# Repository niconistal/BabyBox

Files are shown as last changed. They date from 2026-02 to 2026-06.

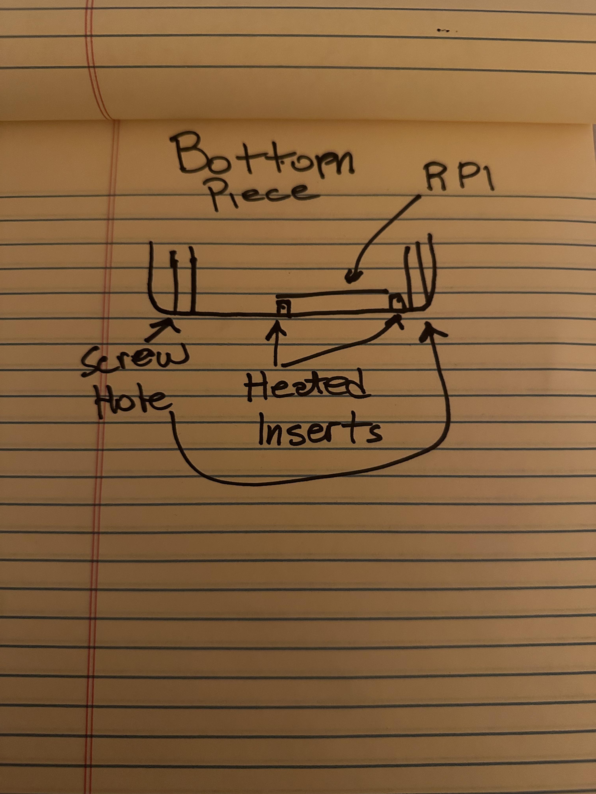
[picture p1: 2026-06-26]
hardware/sketches/sketch-bottom-piece.jpeg

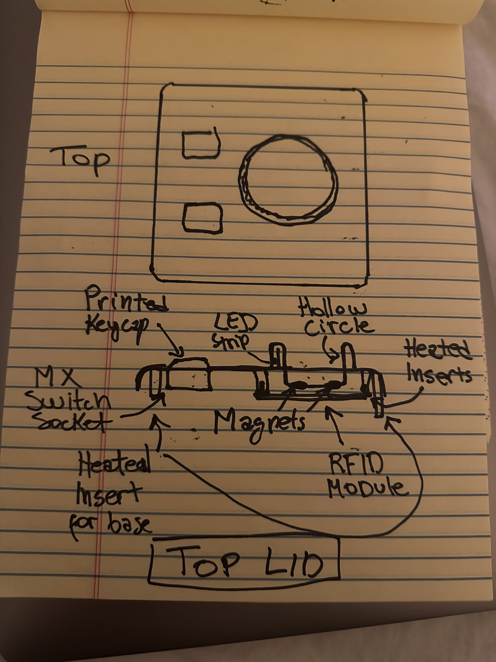
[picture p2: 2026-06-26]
hardware/sketches/sketch-top-and-lid.jpeg

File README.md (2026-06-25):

<div align="center">

# 🧸 BabyBox

### A screen-free, figurine-driven media player for toddlers

*Place a 3D-printed character on the box — its song or video plays. No menus, no screens, no swiping.*

BabyBox render — a soft white box with a glowing rainbow LED strip and a pink figurine on top








</div>

---

## What it is

BabyBox is a tangible, Montessori-friendly media player built around a Raspberry Pi. A child plays content by **physically placing a figurine** on top of the box — each figurine hides an RFID tag and magnets, so it snaps into place and is detected instantly. Parents curate content from a phone or laptop via a web UI; kids interact with nothing but the toys.

It's a full-stack hardware project: **embedded software, a parent web app, parametric 3D-printed hardware, and the audio/Bluetooth plumbing** to tie it together.

> [!NOTE]
> This is a personal/portfolio build. It demonstrates end-to-end ownership of a physical product — from OpenSCAD CAD and GPIO wiring up through a tested Python service and a Flask UI — including a hardware-abstraction layer that lets the entire system run and be tested **on a laptop with no Raspberry Pi attached**.

---

## How it works

```
   Figurine                Raspberry Pi Zero 2 W
 (RFID + magnets)     ┌───────────────────────────┐
        │             │                           │
        ▼   SPI       │   ┌─────────┐             │──── HDMI ───► TV   (video only)
   ┌─────────┐  ┌────►│   │   mpv   │  playback   │
   │ box top │──┘     │   └─────────┘             │──── BT A2DP ► Speaker (all audio)
   │ RFID +  │        │                           │
   │ magnets │        │   Flask web UI  ◄── WiFi ─┼──── 📱 Parent's phone / laptop
   └─────────┘        └───────────────────────────┘
```

1. **Tap to play** — a figurine is placed; the MFRC522 reader picks up its RFID UID.
2. **Map & play** — the controller looks up the tag → media mapping (SQLite) and plays it with `mpv`.
3. **Split A/V** — video goes to the TV over HDMI; *all* audio is routed to a Bluetooth speaker (placed near the child at a safe volume).
4. **Playback lock** — once content starts, new figurines are ignored until it finishes. No toddler content-hopping.
5. **Parents stay in control** — a web UI handles YouTube downloads (`yt-dlp`), figurine assignment, daily video limits, and history.

---

## Highlights

| | |
|---|---|
| 🎯 **Zero-screen interface for kids** | The only "UI" a toddler touches is a physical toy. RFID + magnets give a satisfying snap and reliable reads. |
| 🔌 **Mock/real hardware abstraction** | A factory + `base` interfaces swap real GPIO drivers for mocks via `BABYBOX_ENV=dev`. The whole stack runs and is unit-tested off-Pi. |
| 📺 **Split audio/video routing** | Picture on the TV (HDMI), sound on a portable Bluetooth speaker — solved with a non-trivial PipeWire/WirePlumber config. |
| ⏳ **Real parental controls** | Per-day video limits (count *and* minutes), 6 AM reset, audio always unlimited, with gentle LED + buzzer "last video / all done" feedback. |
| 🧩 **Parametric 3D-printed hardware** | OpenSCAD enclosure + figurine bases with pause-and-insert magnet pockets (fully sealed = toddler-safe). Includes a custom "burgerdog" multi-color mascot. |
| 🧠 **Robust by design** | Falls back to HDMI audio if the speaker is off; de-dupes rapid RFID reads; a finite-state playback machine keeps behavior predictable. |

---

## Tech stack

| Layer | Tech |
|---|---|
| **Core service** | Python 3, threaded RFID/button loops, FSM controller |
| **Media** | `yt-dlp` (download) · `mpv` via `python-mpv` (playback) |
| **Audio** | PipeWire + WirePlumber (Bluetooth A2DP, no-suspend config) |
| **Hardware** | MFRC522 RFID (SPI) · WS2812 LEDs · passive buzzer · 2 buttons |
| **Web UI** | Flask + vanilla HTML/JS (no build step) |
| **Storage** | SQLite (single file, zero-config) |
| **CAD** | OpenSCAD (parametric, code-defined) → STL → Bambu Studio |
| **Ops** | systemd services · `setup.sh` provisioning |
| **Tests** | pytest (controller, limits, db) |

---

## Getting started (dev mode — no Pi required)

The hardware layer mocks itself, so you can run the full service on macOS/Linux:

```bash
cd software
python -m venv .venv && source .venv/bin/activate
pip install -r requirements.txt

# Run with mock hardware + web UI
BABYBOX_ENV=dev BABYBOX_DATA_DIR=./_data python -m software.main
# → web UI at http://localhost:8080

# Run the test suite
pytest
```

In dev mode, "scanning a figurine" and button presses are simulated through the mock drivers, and media playback is stubbed — so you can exercise the controller, limits, and web UI end-to-end without any electronics.

### On the Raspberry Pi

```bash
# Raspberry Pi OS Lite — enable SPI, install system deps, BT config, systemd units
sudo ./scripts/setup.sh
```

This installs the Pi-only drivers (`mfrc522`, `rpi_ws281x`, `RPi.GPIO`), the WirePlumber Bluetooth fixes (`scripts/wireplumber/`), and registers the `babybox` + Bluetooth auto-connect services. The parent UI is then reachable at **`http://babybox.local`**.

---

## Repository layout

```
BabyBox/
├── software/            # Python service
│   ├── main.py          #   entry point — wires hardware, controller, web together
│   ├── controller.py    #   playback state machine + video-limit logic
│   ├── player.py        #   mpv wrapper (split A/V output)
│   ├── downloader.py    #   yt-dlp wrapper (MP4 video / MP3 audio)
│   ├── bluetooth.py     #   speaker pairing + auto-connect
│   ├── limits.py        #   daily video-limit enforcement
│   ├── db.py / models.py#   SQLite layer + data classes
│   ├── hardware/        #   ⭐ base interfaces + mock/ and real/ drivers (factory)
│   ├── web/             #   Flask app (dashboard, library, figurines, settings, history)
│   └── tests/           #   pytest suite
├── hardware/
│   ├── enclosure/       #   babybox-case.scad — parametric box
│   └── figurines/       #   base template + "burgerdog" multi-layer mascot
├── scripts/             #   setup.sh, systemd units, WirePlumber configs, STL gen
├── renders/             #   Blender renders + exported STLs
├── docs/                #   printable assembly guide (PDF + generator)
├── website/             #   marketing site (deployed via GitHub Pages)
└── SPEC.md              #   full design spec (hardware, software, BoM, decisions)
```

---

## Hardware (bill of materials)

Roughly **~$51** total if you already own a Bluetooth speaker:

Raspberry Pi Zero 2 W · MicroSD · MFRC522 RFID module + MIFARE coin stickers · WS2812 LED strip · passive buzzer · 2 buttons · neodymium magnets (6×3 mm) · 5V/3A supply · mini-HDMI cable · 3D-printed enclosure & figurines (Bambu Lab P2S).

Full BoM, GPIO pinout, wiring, and design rationale live in **[`SPEC.md`](SPEC.md)**.

---

## Design decisions worth calling out

- **Figurine = the interface.** RFID coin stickers are invisible to the child and embedded in the toy; magnets guarantee the tag lands over the antenna every time.
- **Magnets are sealed inside the print** using a pause-and-insert technique (solid layers above and below) — they cannot be removed or swallowed.
- **Audio over Bluetooth, not the Pi jack** — portable, volume-safe near the child, and frees GPIO 18 for the LED strip. The tradeoff was a finicky shared-radio Bluetooth stack, fixed with two WirePlumber configs.
- **Playback lock over a "stop and switch" model** — toddlers will otherwise swap figurines endlessly. Content must finish; the stop button is a parent escape hatch.
- **Code-defined CAD (OpenSCAD)** — the enclosure is parametric and diff-able, not a binary blob.

---

<div align="center">

*Built as a portfolio project — a small physical product taken from spec to (almost) toddler-tested.*

See **[`SPEC.md`](SPEC.md)** for the complete design document.

</div>

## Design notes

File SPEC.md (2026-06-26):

# BabyBox — Toddler Media Player

## Overview

BabyBox is a toddler-friendly media player powered by a Raspberry Pi. The child places
a 3D-printed figurine on top of the box to play a song or video. Each figurine has an
RFID tag and magnets embedded inside. The box has matching magnets and an RFID reader
under the top surface, so the figurine snaps into place and is detected instantly.

Parents add content by pasting YouTube URLs into a web UI. The system downloads
the video and saves it locally — either as video (MP4) or audio-only (MP3),
depending on what the parent chooses. A daily video limit prevents excessive screen
time while audio remains unrestricted.

**Output routing:** Video goes to the TV via HDMI. All audio goes to a Bluetooth
speaker. For video content, the picture is on the TV and the sound comes from the
Bluetooth speaker.

**Playback lock:** Once content starts playing, it must finish before a new figurine is
accepted. Figurines placed during playback are ignored. This prevents a toddler from
endlessly swapping between content.

---

## 1. User Stories

| Who | What |
|---|---|
| Child  | Places a figurine on the box and the associated song/video starts |
| Child  | Sees a fun LED animation when a figurine is placed |
| Child  | Places figurines during playback — nothing happens (content must finish)|
| Child  | Gets a "last video" warning (LED + buzzer) when 1 video remains |
| Child  | Gets a "all done" feedback (LED + buzzer) when video limit is reached |
| Parent | Pastes a YouTube URL, picks audio or video, system downloads it |
| Parent | 3D-prints figurines and embeds RFID tags + magnets |
| Parent | Assigns a figurine to a downloaded media file via the web UI |
| Parent | Sets a daily video limit (e.g., 3 videos or 45 min/day) |
| Parent | Sees playback history / daily stats on the web UI |

---

## 2. Hardware

### 2.1 Bill of Materials

| Component | Source | Est. Cost |
|---|---|---|
| Raspberry Pi Zero 2 W | Purchase | ~$15 |
| MicroSD card (32 GB+) | Purchase | ~$8 |
| MFRC522 RFID Module | Kit | -- |
| RFID sticker tags (MIFARE 13.56 MHz, 25mm coin type) | Purchase (10x) | ~$5 |
| Neodymium magnets (6x3mm disc, 20x) | Purchase  | ~$5 |
| Bluetooth speaker | Already owned / Purchase | ~$0-20 |
| WS2812B RGB 8-LED flexible strip (60/m, SunFounder kit) | Kit | -- |
| MX (Cherry-compatible) keyswitches (x2: play/pause, stop) | Purchase | ~$2 |
| Brass heat-set inserts (M3 x8, M2.5 x4, M2 x4)  | Purchase | ~$3 |
| M3 / M2.5 / M2 machine screws (assorted) | Purchase | ~$2 |
| Passive Buzzer | Kit | -- |
| Resistors / wires (soldered — no breadboard) | Kit | -- |
| 5V 3A micro USB power supply | Purchase | ~$8 |
| Mini HDMI to HDMI cable | Purchase | ~$5 |
| 3D-printed enclosure + figurines| Bambu Lab P2S | ~$5 |
| **Total (if speaker owned)** | | **~$56**  |

### 2.2 Why Pi Zero 2 W?

- Cheapest Pi with quad-core ARM (1 GHz) and hardware H.264 decode
- Built-in WiFi for the parent web UI (no extra dongles)
- Built-in Bluetooth for connecting to the speaker
- Enough GPIO for RFID, LEDs, buttons, and buzzer
- HDMI output for video to TV
- Runs headless Raspberry Pi OS Lite with minimal overhead

### 2.3 Output Routing

```
                    ┌──────────────┐
                    │  Raspberry   │
   Figurine         │  Pi Zero 2 W │
   (RFID + magnet)  │              │
     ▼         SPI  │  ┌────────┐  │──── HDMI ────► TV (video only)
   [Box top] ──────►│  │  mpv   │  │
                    │  └────────┘  │──── Bluetooth ► Speaker (all audio)
                    │              │
                    └──────────────┘
```

**Video content:** Picture on TV via HDMI, audio routed to Bluetooth speaker via
PulseAudio/PipeWire.

**Audio content:** Sound plays on Bluetooth speaker only. TV can be off or show an
idle screen.

**Why split?** The Bluetooth speaker can be placed near the child at a safe volume,
while the TV can be further away. Volume is controlled on the speaker itself.

> **Wired-speaker variant:** an alternative build that replaces the Bluetooth
> speaker with a salvaged IKEA KALLSUP driver wired to a MAX98357A I2S amp —
> see [`hardware/wired-speaker/SCHEMATIC.md`](hardware/wired-speaker/SCHEMATIC.md).

### 2.4 GPIO Pin Assignment

```
Pi Zero 2 W GPIO Layout
========================

MFRC522 (SPI0):
  SDA  → GPIO 8  (CE0)
  SCK  → GPIO 11 (SCLK)
  MOSI → GPIO 10 (MOSI)
  MISO → GPIO 9  (MISO)
  RST  → GPIO 25
  3.3V → 3.3V
  GND  → GND

WS2812 LED Strip:
  DIN  → GPIO 18 (PWM0)
  5V   → 5V
  GND  → GND

Buttons (active low, internal pull-up):
  Play/Pause → GPIO 17
  Stop       → GPIO 27

Passive Buzzer:
  Signal → GPIO 12 (PWM1)
  GND    → GND
```

No I2S DAC conflicts since audio goes over Bluetooth, so GPIO 18 is free for the
WS2812 strip.

---

## 3. Software Architecture

```
┌───────────────────────────────────────────────────────┐
│                     BabyBox OS                        │
│              (Raspberry Pi OS Lite + PulseAudio)      │
├───────────────────────────────────────────────────────┤
│                                                       │
│  ┌────────────┐  ┌─────────────┐  ┌────────────────┐ │
│  │ RFID       │  │ Media       │  │ LED / Buzzer   │ │
│  │ Listener   │  │ Player      │  │ Feedback       │ │
│  │ (mfrc522)  │  │ (mpv)       │  │ Controller     │ │
│  └─────┬──────┘  └──────▲──────┘  └───────▲────────┘ │
│        │                │                 │           │
│  ┌─────▼──────────────────────────────────┴────────┐  │
│  │           Core Controller (Python)              │  │
│  │  - Tag → media mapping (SQLite)                 │  │
│  │  - Playback state machine (with lock)           │  │
│  │  - Video limit enforcement                      │  │
│  │  - Button input handling                        │  │
│  │  - Bluetooth speaker connection management      │  │
│  └─────────────────────▲───────────────────────────┘  │
│                        │                              │
│  ┌─────────────────────▼───────────────────────────┐  │
│  │           Parent Web UI (Flask)                 │  │
│  │  - Map figurines to media files                 │  │
│  │  - Set video limits                             │  │
│  │  - View playback history                        │  │
│  │  - Upload media                                 │  │
│  │  - Bluetooth speaker pairing                    │  │
│  └─────────────────────────────────────────────────┘  │
│                                                       │
│  ┌─────────────────────────────────────────────────┐  │
│  │           PulseAudio / PipeWire                 │  │
│  │  - Default audio sink → Bluetooth speaker       │  │
│  │  - HDMI sink → video only (no audio)            │  │
│  └─────────────────────────────────────────────────┘  │
│                                                       │
└───────────────────────────────────────────────────────┘
```

### 3.1 Tech Stack

| Layer | Technology | Why |
|---|---|---|
| Language | Python 3 | Best RPi GPIO ecosystem |
| RFID | `mfrc522` Python lib (SPI) | Direct support for MFRC522 |
| Media download  | `yt-dlp` | YouTube download, audio extract|
| Media playback  | `mpv` (via python-mpv) | Lightweight, HW-accelerated |
| Audio routing | PulseAudio | Bluetooth A2DP sink support |
| LED control | `rpi_ws281x` | Native WS2812 driver |
| Database | SQLite | Zero config, single file |
| Web UI | Flask + vanilla HTML/JS | Lightweight, no build step |
| Process mgmt | systemd services | Auto-start on boot |

### 3.2 Data Model

```sql
-- Media files stored on disk at /home/pi/babybox/media/{audio,video}/
CREATE TABLE media (
    id          INTEGER PRIMARY KEY,
    title       TEXT NOT NULL,
    filename    TEXT NOT NULL,          -- relative to media dir
    media_type  TEXT NOT NULL,          -- 'audio' | 'video'
    source_url  TEXT,                   -- original YouTube URL
    thumbnail   TEXT,                   -- path to downloaded thumbnail
    duration_s  INTEGER,               -- duration in seconds
    created_at  TIMESTAMP DEFAULT CURRENT_TIMESTAMP
);

-- RFID tag to media mapping (each tag is inside a figurine)
CREATE TABLE tags (
    uid         TEXT PRIMARY KEY,       -- RFID tag UID (hex string)
    media_id    INTEGER NOT NULL,
    label       TEXT,                   -- friendly name ("Elsa figurine")
    created_at  TIMESTAMP DEFAULT CURRENT_TIMESTAMP,
    FOREIGN KEY (media_id) REFERENCES media(id)
);

-- Playback log for stats and limit enforcement
CREATE TABLE playback_log (
    id          INTEGER PRIMARY KEY,
    media_id    INTEGER NOT NULL,
    tag_uid     TEXT,
    started_at  TIMESTAMP DEFAULT CURRENT_TIMESTAMP,
    ended_at    TIMESTAMP,
    completed   BOOLEAN DEFAULT FALSE,
    FOREIGN KEY (media_id) REFERENCES media(id)
);

-- Parental controls
CREATE TABLE settings (
    key         TEXT PRIMARY KEY,
    value       TEXT NOT NULL
);
-- Default settings:
--   daily_video_limit_count  = 5
--   daily_video_limit_minutes = 60
--   limit_reset_hour = 6          (reset at 6 AM)
--   bt_speaker_mac = ""           (paired Bluetooth speaker MAC address)
```

### 3.3 Core State Machine

```
              ┌──────────┐
    ┌─────────│   IDLE   │◄─────────────────────────────┐
    │         └────┬─────┘                              │
    │              │ figurine placed                     │
    │              ▼                                    │
    │    ┌──────────────────┐                           │
    │    │ CHECK LIMITS     │                           │
    │    │ (video only)     │                           │
    │    └──┬────────┬──────┘                           │
    │       │ OK     │ exceeded                         │
    │       ▼        ▼                                  │
    │  ┌────────┐  ┌──────────────┐                     │
    │  │LOADING │  │ ALL DONE     │                     │
    │  │(LEDs)  │  │ (buzzer+LED) │─────────────────────┘
    │  └──┬─────┘  └──────────────┘
    │     │
    │     │ last video?
    │     ├────yes──► "last video" warning (buzzer + yellow LEDs)
    │     │           then continue to PLAYING
    │     │
    │     ▼
    │  ┌───────────────────┐
    │  │ PLAYING           │ ◄── figurines placed here are IGNORED
    │  │ (audio or video)  │
    │  │                   │──── stop button → IDLE
    │  └───────┬───────────┘
    │          │ playback ends naturally
    │          ▼
    │  ┌───────────────────┐   was last video?
    │  │ FINISHED          │──────yes──► "all done" feedback
    │  │ (log playback)    │              (buzzer + red→off LEDs)
    │  └───────┬───────────┘              then → IDLE
    │          │ no
    └──────────┘
```

**Key behaviors:**

**Playback lock**
- While in PLAYING state, all RFID scans (figurines placed) are silently ignored
- Content must finish on its own (or be stopped via the stop button)
- The stop button is a parent escape hatch, not intended for the child
- After content finishes, the system returns to IDLE and accepts new figurines

**Last video warning**
- When the child starts what will be their last allowed video, the box signals
  "this is the last one" before playback begins
- Short buzzer melody (gentle, not alarming) + LEDs pulse yellow briefly
- Playback proceeds normally after the warning

**All done feedback**
- When the last video finishes, or when a figurine is placed after the limit is
  reached, the box signals "no more videos today"
- Distinct buzzer melody (calm, final-sounding) + LEDs pulse red then fade off
- Audio figurines still work normally — only video is limited

---

## 4. Video Limit System

- Limits tracked per calendar day (resets at configurable hour, default 6 AM)
- Two limit modes (whichever is hit first):
  - **Count-based:** max N videos per day
  - **Time-based:** max M minutes of video per day
- Audio content is never limited — only video counts against the daily allowance
- Parents can override / adjust limits via web UI

### Feedback stages

| Moment | Buzzer | LEDs |
|---|---|---|
| **Last video starting** | Gentle ascending tone (short) | Pulse yellow 3x, then normal  |
| **Last video finished** | Calm descending melody | Pulse red 3x, then fade off |
| **Limit already reached** (figurine placed, no videos left) | Same descending melody | Same red pulse + fade off |

The two feedback patterns are intentionally distinct so the child learns to
associate them:
- **Yellow / ascending** = "one more, then we're done"
- **Red / descending** = "all done for today, let's do something else"

---

## 5. Bluetooth Audio Setup

The Pi Zero 2 W connects to a Bluetooth speaker over A2DP (Advanced Audio
Distribution Profile) using PulseAudio.

### Auto-connect on boot
- The speaker MAC address is stored in the database
- A systemd service runs on boot that:
  1. Powers on the Bluetooth adapter
  2. Connects to the paired speaker
  3. Sets it as the default PulseAudio sink
- If the speaker is off or out of range, audio falls back to HDMI

### mpv audio routing
- mpv is configured with `--audio-device=pulse` so all audio goes through PulseAudio
- PulseAudio's default sink is the Bluetooth speaker
- For video, mpv sends video to HDMI framebuffer and audio to PulseAudio (BT speaker)
- For audio-only, mpv just outputs to PulseAudio (BT speaker)

### Pairing flow (one-time, via web UI)
1. Parent opens Settings page
2. Puts Bluetooth speaker in pairing mode
3. Clicks "Scan for speakers" in the web UI
4. Selects the speaker from discovered devices
5. System pairs, trusts, and saves the MAC address

---

## 6. Figurines

Each figurine is a small 3D-printed character or object that the child places on top
of the box to trigger playback. Figurines are the primary interface — no screens or
menus for the child.

### 6.1 Construction

Each figurine contains two embedded components:

```
    ┌─────────┐
    │  ╭───╮  │  ← 3D-printed shell (two halves or cavity)
    │  │   │  │
    │  ╰───╯  │
    │ ┌─────┐ │
    │ │RFID │ │  ← MIFARE 13.56 MHz coin sticker tag (25mm)
    │ │stickr│ │    glued flat inside the base
    │ └─────┘ │
    │ (•) (•) │  ← 2x neodymium disc magnets (6x3mm)
    │         │    fully enclosed inside printed base
    └─────────┘
```

- **RFID sticker tag:** 25mm diameter coin-type, self-adhesive, stuck to the inside
  floor of the figurine. Must sit within ~25mm of the MFRC522 antenna (through the
  box top wall) for reliable reads.
- **Magnets:** 2x neodymium disc magnets (6mm diameter x 3mm thick) fully enclosed
  inside the printed base using a pause-and-insert technique: the print is paused at
  the correct Z height, magnets are dropped into the cavities, and printing resumes
  to seal them with solid layers above. This makes magnets impossible to remove —
  critical for toddler safety. Polarity must match the box magnets (attract, not repel).

### 6.2 Design Guidelines

- **Size:** 40-60mm tall, 30-40mm base diameter — easy for toddler hands to grab
- **Base:** Flat, ~5mm thick, with printed cavities for magnets and space for RFID tag
- **Shell:** Print in two halves (top + base) that snap or glue together after
  inserting the tag and magnets. Or print with a cavity and a press-fit lid.
- **Style:** Simple, recognizable shapes — animals, vehicles, characters.
  Minimal overhangs so they print without supports.
- **Material:** PLA or PETG, bright colors. Bambu Lab P2S supports multi-color
  with the AMS, so figurines can be printed in multiple colors in one go.
- **Safety:** No small detachable parts. Magnets are fully enclosed inside the
  printed base using pause-and-insert (sealed with solid layers above and below).
  A toddler cannot access or remove them.

### 6.3 Figurine Base (standard across all figurines)

All figurines share the same base dimensions so they align with the box magnets:

```
        Top view of figurine base
        ┌───────────────────┐
        │                   │
        │   (•)       (•)   │  ← magnet pockets (6mm dia, 3mm deep)
        │                   │     20mm apart center-to-center
        │   ┌───────────┐   │
        │   │   RFID    │   │  ← RFID sticker (25mm coin)
        │   │  sticker  │   │    centered
        │   └───────────┘   │
        │                   │
        └───────────────────┘
              35mm wide
```

### 6.4 RFID Read Distance

- MFRC522 typical read range: **~30mm** through air
- The signal must pass through: box top wall (~3mm) + figurine base (~5mm) = ~8mm
- This leaves ~22mm margin — more than enough for reliable reads
- The RFID antenna on the MFRC522 board is positioned directly under the box top
  surface, centered on the magnet alignment point

---

## 7. Enclosure (3D Printed — OpenSCAD)

The enclosure is defined as parametric OpenSCAD code, generated by Claude Code.
OpenSCAD renders the model to STL, which is then sliced in Bambu Studio.

> **Current revision: v3** (`hardware/enclosure/babybox-case-v3.scad`
> + `keycaps.scad`) — a compact 90 x 90 mm box (body only ~47 mm tall) drawn
> from the paper sketches in `hardware/sketches/`. The top is a **raised, sealed
> LED ring around a recessed hole**: the figurine drops straight in and the RFID
> reader sits flush right beneath it. Three printable parts plus accessories:
>
> | Part | File / `render_part` | Notes |
> |------|----------------------|-------|
> | **Bottom tray** | `v3 / "tray"` | Pi Zero 2 W + buzzer mount here (M2.5 / press-fit), bumper feet, floor vents, engraved logo |
> | **Body** | `v3 / "body"` | Short open tube; 4 full-height corner **columns** with a heat-set insert at each end; one tiny power-cable hole on the back, lined up with the Pi's micro-USB power port (no video/HDMI exposed) |
> | **Top plate** | `v3 / "top"` | RAISED sealed LED ring + RECESSED figurine hole; magnets in the hole floor (pause-and-insert); MFRC522 flush underneath (antenna up); 2x **MX** button cut-outs |
> | **Diffuser ring** | `v3 / "diffuser"` | Print translucent/natural; glued over the strip — caps the top + outer face so the LED strip is fully sealed |
> | **Keycaps** | `keycaps.scad / "play"`,`"stop"` | **Big round** custom caps with engraved icons, press onto the MX stems |
>
> **What changed from v2:**
> - **Soldered build, no breadboard** — everything hand-wired to the Pi header.
> - **Heat-set brass inserts everywhere** (not self-tapping) so it opens/closes
>   forever: tray bolts up into the column bottoms, top plate bolts down into
>   the column tops, Pi/RFID screw onto inserts.
> - **MX keyswitches with big round 3D-printed keycaps** instead of panel buttons.
> - **Sealed LED ring** — the SunFounder 8x WS2812B 60/m flexible strip wraps the
>   hole wall (wrap dia ~42 mm) and is fully covered by a glued translucent
>   diffuser cap: it glows as a ring, with no exposed strip for little fingers.
> - **Recessed figurine hole** — the figurine drops *into* a central hole (not
>   onto a raised lid). The MFRC522 mounts flush under the thin hole floor, so
>   the tag ends up ~5–7 mm from the antenna (well under the ~30 mm range).
>   Magnets sit in the hole floor (pause-and-insert) for a gentle snap.
> - **Only as tall as needed** — the body shrank to ~32 mm (just clears the Pi).
>
> The v2 "Pebble" (`babybox-case-v2.scad`) and the v1 design below remain for
> reference. Figurine base / magnet / RFID coin geometry is unchanged, so all
> existing figurines still work.
>
> Shared component dimensions (LED strip, MX switch/keycap, heat-set inserts)
> live in `hardware/common-params.scad`.

Design goals for the Bambu Lab P2S printed enclosure:

- **Toddler-proof:** Rounded corners, thick walls (3mm+), no small parts
- **Top surface:** Flat RFID scan area with a printed visual marker (circle, paw print,
  star, etc.) showing where to place figurines. Magnets embedded under the surface
  to hold figurines in place.
- **Front:** 2 large buttons (play/pause, stop), LED strip window
- **Side:** Micro SD card slot access (behind a cover)
- **Back:** Mini HDMI port access, 2x micro USB (OTG + power)
- **Internal:** Snap-fit or screw mount points for Pi, RFID module, LED strip
- **LED window:** Translucent or open slot for WS2812 strip to shine through
- **No speaker grille needed** — audio goes to external Bluetooth speaker
- **Size:** Approx. 150mm x 110mm x 75mm (fits breadboard, fits on P2S build plate)
- **Print:** PETG or PLA+, no supports needed if designed with flat faces

### 7.1 Box Top — Magnet and RFID Layout

```
    Cross-section of box top (figurine placed)

    ══════════════════════════  ← figurine base (6mm)
    │(•)│    │RFID stickr│ │(•)│  magnets fully enclosed inside base
    ──────────────────────────
    ┃         3mm wall        ┃  ← box top wall
    ┃  (•)  ┌──────────┐ (•) ┃  ← box magnets fully enclosed in lid
    ┃       │ MFRC522  │     ┃  ← RFID module mounted directly under the wall
    ┃       │ antenna  │     ┃
    ┃       └──────────┘     ┃
```

- **Box magnets:** 2x neodymium disc magnets (6x3mm) fully enclosed in the box lid
  using pause-and-insert during printing (same technique as figurine base).
  Lid prints upside-down; magnets are inserted at the correct pause height.
- **Magnet alignment:** Figurine magnets and box magnets are 20mm apart
  center-to-center. This creates a satisfying snap when the figurine is placed and
  ensures consistent positioning over the RFID antenna.
- **MFRC522 mounting:** The module is mounted face-up directly under the top wall,
  centered between the magnets. The antenna coil faces upward toward the figurine.

### 7.2 Enclosure Sketch (v3 "Tower")

```
   TOP VIEW                         SIDE VIEW (figurine dropped in)
   ┌────────────────────┐                     ┌─┐  ← figurine sticks up
   │     .-"""""-.      │            ___      │ │     out of the hole
   │   (  (( O ))  )    │ ← raised  /(( ))\ ──┤ ├── ← raised sealed LED ring
   │    `-.._____.-`    │   sealed ┌┴─────┴┐  └─┘     (figurine RECESSED in
   │                    │   ring   │ MFRC522│            the hole below it)
   │   (▶❚❚)     ( ◼ )   │          ├────────┤  ← RFID flush under the floor
   │   play      stop   │ ← round  │  BODY  │‹═ power hole at the Pi port
   └────────────────────┘   caps   │ tray:Pi│
        90 x 90 mm                  └────────┘
                                    body ~47 mm tall
   The figurine drops INTO the centre hole and sits recessed; the MFRC522
   reads it through the thin floor (~5 mm). The flexible LED strip wraps the
   hole wall and is fully sealed under a glued translucent diffuser cap.
```

The flexible WS2812B strip wraps the 40 mm hub; the translucent **diffuser
ring** slips over it and turns the 8 LEDs into a soft ring of light around the
figurine. The two **MX switches** carry big round printed keycaps. Everything
is held with **heat-set inserts** — four corner columns run the full height of
the body with an insert at each end (tray bolts up, top plate bolts down).

---

## 8. Parent Web UI

Accessible at `http://babybox.local` (mDNS) from any device on the same WiFi.

### Pages:

1. **Dashboard** — now playing, today's video count/limit, quick stats
2. **Media Library** — list all downloaded media (with thumbnails), add new from
   YouTube, delete. Shows download progress for pending items.
3. **Figurine Manager** — place a figurine on the box → assign to media, label it,
   list all mappings
4. **Settings** — video limits, Bluetooth speaker pairing, WiFi config, shutdown/reboot
5. **History** — playback log, daily/weekly charts

### Add Media Flow (YouTube download):
1. Parent opens Media Library page
2. Pastes a YouTube URL
3. Chooses save mode: **Video** (MP4) or **Audio only** (MP3)
4. Clicks "Download"
5. System uses `yt-dlp` to download in the background:
   - **Video mode:** downloads best quality MP4 (up to 1080p) + thumbnail
   - **Audio mode:** extracts audio track, converts to MP3 + thumbnail
6. Progress bar shows download status
7. Once complete, media appears in the library with title and thumbnail
   auto-populated from YouTube metadata

### Figurine Assignment Flow:
1. Parent opens Figurine Manager page
2. Clicks "Register New Figurine"
3. Places figurine on the box
4. Web UI shows the detected RFID tag UID
5. Parent selects a media file from the library (shows thumbnails)
6. Parent gives figurine a friendly name (e.g., "Blue dinosaur")
7. Saves → figurine is now mapped

---

## 9. Project Structure

```
BabyBox/
├── SPEC.md
├── README.md
├── hardware/
│   ├── wiring-diagram.md         # Fritzing or text-based wiring guide
│   ├── enclosure/                # Box OpenSCAD source + exported STL
│   │   ├── babybox-case.scad     # Parametric enclosure (Claude Code generated)
│   │   ├── babybox-lid.scad      # Lid with magnet pockets + RFID mount
│   │   └── README.md             # How to render and print
│   └── figurines/                # Figurine 3D print files
│       ├── base-template.scad    # Parametric base (Claude Code generated)
│       ├── dino.stl              # Example figurine (Meshy AI generated)
│       └── bunny.stl             # Example figurine (Meshy AI generated)
├── software/
│   ├── requirements.txt
│   ├── config.py                 # Paths, GPIO pins, defaults
│   ├── main.py                   # Entry point, orchestrates everything
│   ├── rfid.py                   # RFID listener (MFRC522)
│   ├── player.py                 # Media playback (mpv wrapper)
│   ├── downloader.py             # YouTube download (yt-dlp wrapper)
│   ├── bluetooth.py              # Bluetooth speaker connection mgmt
│   ├── leds.py                   # WS2812 LED animations
│   ├── buzzer.py                 # Buzzer feedback patterns
│   ├── buttons.py                # Physical button handler
│   ├── limits.py                 # Video limit enforcement
│   ├── db.py                     # SQLite database layer
│   ├── models.py                 # Data classes
│   └── web/
│       ├── app.py                # Flask app
│       ├── templates/
│       │   ├── base.html
│       │   ├── dashboard.html
│       │   ├── library.html
│       │   ├── figurines.html
│       │   ├── settings.html
│       │   └── history.html
│       └── static/
│           ├── style.css
│           └── app.js
├── scripts/
│   ├── setup.sh                  # System setup (deps, SPI, Bluetooth, etc.)
│   ├── babybox.service           # systemd unit file
│   └── bt-connect.service        # systemd unit for Bluetooth auto-connect
└── media/                        # Downloaded content lives here
    ├── audio/                    # MP3 files (audio-only downloads)
    ├── video/                    # MP4 files (video downloads)
    └── thumbnails/               # YouTube thumbnails for the web UI
```

---

## 10. Implementation Phases

### Phase 1 — Core MVP
- YouTube download via `yt-dlp` (video as MP4, audio-only as MP3)
- RFID scanning → media playback (video via HDMI, audio via Bluetooth speaker)
- Bluetooth speaker pairing and auto-connect on boot
- SQLite database with figurine-to-media mapping
- Playback lock (ignore figurines while playing, wait for content to finish)
- Basic CLI tool to register figurines
- Auto-start on boot

### Phase 2 — Physical Controls & Feedback
- Button handling (play/pause, stop)
- WS2812 LED animations (scan feedback, now playing, idle pulse)
- Buzzer feedback (scan confirm, error, limit reached)

### Phase 3 — Parental Controls
- Video limit enforcement (count + time based)
- Web UI: YouTube download (paste URL, pick audio/video), figurine management, settings
- Bluetooth speaker management in web UI
- Playback history and stats

### Phase 4 — Enclosure & Figurines
- OpenSCAD enclosure (parametric, generated by Claude Code, rendered to STL)
- OpenSCAD figurine base template (parametric, generated by Claude Code)
- First set of figurine tops (3-5 designs via Meshy AI, merged with base in Blender)
- Magnet polarity testing and assembly
- Final testing with actual toddler

---

## 11. Key Design Decisions

| Decision | Choice | Rationale |
|---|---|---|
| Language | Python | Best GPIO/hardware library support |
| Content source | YouTube (via yt-dlp) | Vast library, parent curates what to download |
| Media player | mpv | HW-accelerated, scriptable, split A/V out  |
| Database | SQLite | Zero-config, single file, durable |
| Web framework | Flask | Minimal, well-known, fits the Pi |
| LED driver | rpi_ws281x | Native, well-supported |
| RFID protocol | MIFARE 13.56 MHz | What MFRC522 supports |
| RFID form factor | Coin sticker in figurine | Invisible to child, embedded in toy |
| Figurine attachment | Neodymium magnets | Satisfying snap, consistent RFID alignment |
| Video output | HDMI to TV | Native, zero config, full resolution |
| Audio output | Bluetooth speaker | Portable, adjustable, near the child |
| Audio routing | PulseAudio | Built-in Bluetooth A2DP sink support |
| Playback lock | Ignore during play  | Prevents toddler content-hopping |
| Enclosure CAD | OpenSCAD (AI-generated) | Code-based = AI can write it, parametric |
| Enclosure material | PETG | Tougher than PLA, toddler-safe |

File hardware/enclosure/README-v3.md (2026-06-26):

# BabyBox v3 — build guide

Compact box drawn from the paper sketches in `../sketches/`. Soldered build (no
breadboard), brass heat-set inserts throughout, two MX-switch buttons with big
round custom keycaps, and a **raised, sealed WS2812B LED ring** around a
**recessed hole** the figurine drops straight into — with the RFID reader
mounted flush right beneath the hole floor so it reads reliably.

Footprint **90 × 90 mm**, body only **~47 mm** tall (the ring stands ~11 mm
proud; the figurine sticks up out of the hole).

## Parts & how to print

Each part is one `render_part` of `babybox-case-v3.scad` (keycaps are in
`keycaps.scad`). Render: `openscad -o part.stl -D 'render_part="body"' babybox-case-v3.scad`

| Part | `render_part` | Filament | Print orientation | Supports |
|---|---|---|---|---|
| Bottom tray | `tray` | body color | flat, as drawn | none |
| Body tube | `body` | body color | either open end on the bed | none |
| Top plate | `top` | accent color | **right-side up** (underside on the bed); **pause** to drop the ring magnets | none |
| Diffuser ring | `diffuser` | **translucent / natural** (it glows) | flat | none |
| Keycap ×2 | `play`, `stop` (in `keycaps.scad`) | accent color | **top face DOWN** | none |

Two-tone: print body color (tray + body) and accent color (top plate, keycaps)
separately; the diffuser ring in a translucent filament. Figurines come from
`../figurines/`.

### Pause-and-insert magnets (top plate)
Print the top plate right-side up and pause at the height OpenSCAD echoes
(`Z = 4.2 mm`), drop the two **6 × 3 mm** neodymium magnets into the hole-floor
pockets (mind polarity vs. the figurines!), then resume — the floor layers seal
them in, under the figurine and over the RFID.

## Hardware

- **Heat-set inserts** (brass, melted in with a soldering iron):
  - **M3 ×8** — 4 in the body column tops, 4 in the column bottoms
  - **M2.5 ×4** — Pi Zero 2 W standoffs on the tray
  - **M2 ×4** — MFRC522, screwed flush to the top-plate underside
  - Pilot-hole diameters are in `common-params.scad` (`*_insert_hole_dia`);
    nudge them ±0.1 mm to suit your specific inserts.
- **Screws:** M3 (tray→body, top plate→body), M2.5 (Pi), M2 (MFRC522).
- **2× MX (Cherry-compatible) keyswitches** — snap into the 14 × 14 mm plate
  cut-outs (the top plate leaves a 1.5 mm clip shelf).
- **SunFounder 8× WS2812B** 60/m flexible strip (10 mm wide, 2 mm thick).

## Assembly order

1. **Tray:** heat-set the 4× M2.5 inserts, screw the Pi Zero 2 W down, press
   the buzzer into its cradle.
2. **Body:** heat-set the 8× M3 inserts (4 top, 4 bottom of the columns).
3. **Top plate:**
   - heat-set the 4× M2 inserts; screw the MFRC522 **flush** to the underside,
     **antenna-up** under the hole floor (header/pads face down into the body).
   - snap the 2 MX switches into the button cut-outs.
   - wrap the LED strip around the hole wall (adhesive backing sticks to it,
     LEDs facing out), feed the 3 leads down through the wire notch.
   - **glue the diffuser ring** down over the strip — it caps the top and outer
     face so the strip is fully sealed (nothing for little fingers to pick).
4. **Wire everything to the Pi header** (see `../../SPEC.md` §2.4 for pins —
   LED→GPIO18, buttons→GPIO17/27 + GND, buzzer→GPIO12, MFRC522→SPI/CE0).
   Leave a small service loop so the top plate can lift off.
5. **Close it up:** screw the top plate down into the body column tops, set the
   body on the tray and screw it up from underneath, add silicone bumper feet.
6. **Press the round keycaps** onto the MX stems. Drop a figurine into the hole.

## Read-distance sanity

The figurine sits **recessed in the hole**, so its RFID tag ends up only
~**5–7 mm** above the MFRC522 antenna (just the thin hole floor) — well inside
the reader's ~30 mm range. Two **6 × 3 mm** magnets in the hole floor (20 mm
apart) give a gentle snap/hold and align with the figurine-base magnets.

## Tuning (all in `common-params.scad` / the case file header)

- Caps loose/tight on the switches → `mx_stem_arm_t` ∓ 0.05.
- Box too tall/short → `body_h` (currently 32 mm; the assert keeps it tall
  enough for the Pi).
- Different LED strip → set `led_pitch` / `led_count`; the wrap diameter and the
  ring follow `strip_wrap_r` automatically.
- Bigger/smaller round buttons → `mx_keycap_round_dia` (asserts keep them clear
  of the ring and each other).
- Figurine sits too proud/deep → `well_depth`.

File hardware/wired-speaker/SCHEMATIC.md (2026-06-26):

# BabyBox Variant — Wired Speaker (IKEA KALLSUP donor)

A variation of the standard BabyBox build that replaces the Bluetooth speaker with
a **wired speaker driver salvaged from an IKEA KALLSUP** ($10 Bluetooth cube),
driven by a **MAX98357A I2S mono class-D amplifier** on the Pi.

Why wire it instead of using KALLSUP's own Bluetooth?

- No pairing, no reconnect logic, no audio dropouts — audio works the instant the Pi boots
- No battery to charge (or to age inside a toddler's toy)
- Zero Bluetooth latency — button feedback beeps and playback start are instant
- The speaker lives *inside* the BabyBox enclosure: one box, one power cable

---

## 1. Bill of Materials (delta vs. SPEC.md §2.1)

| Change | Component | Est. Cost |
|---|---|---|
| − | Bluetooth speaker | −$0–20 |
| + | IKEA KALLSUP (donor — driver only) | ~$10 |
| + | MAX98357A I2S amp breakout (Adafruit 3006 or clone) | ~$3–6 |
| + | 24 AWG twisted-pair speaker wire (~20 cm) | — |

Everything else (Pi Zero 2 W, MFRC522, LEDs, buttons, buzzer, PSU) is unchanged.
The 5V 3A supply has ample headroom for the amp (≤ ~0.7 A peak at full volume).

### Why the MAX98357A?

- 3.2 W into 4 Ω at 5 V — an exact match for the KALLSUP's 3 W single driver
- I2S digital input: no DAC needed, no analog ground-loop hum, and the
  Pi Zero 2 W has no analog audio jack anyway
- Mono output — correct for the KALLSUP's single full-range driver
  (it mixes (L+R)/2 by default, so stereo media plays fully)

---

## 2. KALLSUP Teardown

1. Peel the four rubber feet and remove the screws beneath them, then split the
   cube (some seams are clipped — pry gently with a spudger).
2. Photograph the board before desoldering anything.
3. **Desolder the speaker driver's two wires** from the Bluetooth PCB
   (or cut them as long as possible if you'd rather not desolder).
4. **Remove the battery**: it's a LiPo pouch/cell. Tape over its leads
   immediately and take it to battery recycling. Never bin a LiPo.
5. The Bluetooth PCB, antenna and buttons are not used — set them aside.
6. Keep: the **driver** (and optionally the cube shell + grille as an external
   speaker pod, if you prefer not to mount the driver inside the BabyBox case).

### Verify the driver before wiring

Measure DC resistance across the driver terminals with a multimeter:

| Reading | Nominal impedance | MAX98357A output @ 5 V | OK?  |
|---|---|---|---|
| ~3.2–3.6 Ω | 4 Ω (expected) | up to 3.2 W | ✅ |
| ~6.4–7.2 Ω | 8 Ω | up to 1.8 W | ✅ (slightly quieter) |
| < 3 Ω | — (suspect) | — | ❌ do not connect |

Note the polarity markings (+ / −) on the driver terminals — keep them for step 4.

---

## 3. GPIO Pin Assignment (changes vs. SPEC.md §2.4)

I2S on the Pi is fixed to GPIO 18/19/21, and GPIO 18 currently drives the
WS2812 strip — so the strip moves to GPIO 13 (PWM1, fully supported by
`rpi_ws281x`).

```
Pi Zero 2 W GPIO Layout — wired-speaker variant
================================================

MFRC522 (SPI0):                          (unchanged)
  SDA  → GPIO 8  (CE0)
  SCK  → GPIO 11 (SCLK)
  MOSI → GPIO 10 (MOSI)
  MISO → GPIO 9  (MISO)
  RST  → GPIO 25
  3.3V → 3.3V
  GND  → GND

MAX98357A (I2S):                         (NEW)
  BCLK → GPIO 18 (PCM_CLK)   physical pin 12
  LRC  → GPIO 19 (PCM_FS)    physical pin 35
  DIN  → GPIO 21 (PCM_DOUT)  physical pin 40
  VIN  → 5V                  physical pin 2 or 4
  GND  → GND
  GAIN → unconnected         (= 9 dB default; see §5)
  SD   → unconnected         (= (L+R)/2 mono mix on Adafruit breakout)

WS2812 LED Strip:                        (MOVED 18 → 13)
  DIN  → GPIO 13 (PWM1)
  5V   → 5V
  GND  → GND

Buttons (active low, internal pull-up):  (unchanged)
  Play/Pause → GPIO 17
  Stop       → GPIO 27

Passive Buzzer:                          (unchanged pin, software PWM)
  Signal → GPIO 12
  GND    → GND
```

> **PWM note:** `rpi_ws281x` claims the hardware PWM block via DMA when driving
> the strip on GPIO 13. Drive the buzzer with **software PWM** (gpiozero's
> default `TonalBuzzer`/`PWMOutputDevice`) — perfectly adequate for beeps.

---

## 4. Schematic

```
                         ┌────────────────────────┐
                         │   Raspberry Pi Zero 2 W│
                         │                        │
   5V PSU ──────────────►│ 5V          HDMI ──────┼────► TV (video only)
   (5V 3A micro-USB)     │                        │
                         │ GPIO18 (PCM_CLK) ──────┼──┐
                         │ GPIO19 (PCM_FS)  ──────┼──┤
                         │ GPIO21 (PCM_DOUT)──────┼──┤
                         │ 5V ────────────────────┼──┤
                         │ GND ───────────────────┼──┤
                         └────────────────────────┘  │
                                                     ▼
                                        ┌─────────────────────┐
                                        │      MAX98357A      │
                                        │  BCLK LRC DIN VIN GND│
                                        │                     │
                                        │   GAIN ─ n/c (9 dB) │
                                        │   SD ─── n/c (mono) │
                                        │                     │
                                        │      +  ▒▒  −       │   twisted pair,
                                        └──────┬──────┬───────┘   24 AWG, ≤20 cm
                                               │      │
                                               +      −
                                        ┌──────┴──────┴───────┐
                                        │  KALLSUP driver     │
                                        │  1.8" full-range    │
                                        │  4 Ω · 3 W (verify) │
                                        └─────────────────────┘
```

**Wiring rules:**

- Amp **+** → driver **+**, amp **−** → driver **−**. Polarity only matters for
  multi-speaker setups, but keep it correct anyway.
- The amp output is a **bridge-tied load (BTL)**: never connect either speaker
  terminal to GND, and never share the speaker wires with other grounds.
- Twist the speaker pair and keep it short to keep class-D switching noise
  away from the RFID antenna. Route it away from the MFRC522.

---

## 5. Gain setting (optional)

Default (GAIN unconnected) is 9 dB, which is right for this driver. To change:

| GAIN pin | Gain  |
|---|---|
| → GND via 100 kΩ | 15 dB |
| → GND directly | 12 dB |
| unconnected | 9 dB  |
| → VIN directly | 6 dB  |
| → VIN via 100 kΩ | 3 dB  |

For a toddler device, consider hard-limiting loudness with **6 dB** (GAIN → VIN)
and relying on software volume below that ceiling.

---

## 6. Software changes

1. **Enable the I2S DAC** in `/boot/firmware/config.txt`:

   ```ini
   dtoverlay=max98357a
   # (or: dtoverlay=hifiberry-dac — same I2S setup, works with clones)
   ```

2. **Audio sink**: the amp appears as an ALSA card. Make it the default
   PulseAudio sink instead of the Bluetooth A2DP sink. The HDMI sink stays
   video-only as before. mpv config is unchanged (`--audio-device=pulse`).

3. **Disable Bluetooth speaker logic** (SPEC.md §5): set `bt_speaker_mac = ""`
   and skip pairing/reconnect at boot. The HDMI audio fallback path is no
   longer needed — wired audio cannot go out of range.

4. **Volume**: the MAX98357A has no hardware volume control. Set the output
   level in software (PulseAudio/ALSA) and expose it in the parent web UI;
   the GAIN ceiling from §5 guarantees a maximum loudness regardless.

5. **LED strip pin**: change the WS2812 GPIO from 18 to **13** in the app
   config, and ensure the buzzer uses software PWM.

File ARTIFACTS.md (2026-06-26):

# BabyBox — Artifacts Spec

This document catalogs every deliverable in the project and the tools and workflows
used to produce them. Artifacts tagged **[AI]** are primarily AI-generated.

---

## Artifact Map

```
BabyBox Artifacts
├── Content (what the child sees and hears)
│   └── [ ] YouTube media (downloaded by parent via web UI)
├── Physical (what the child touches)
│   ├── [AI] Figurines (3D models generated with Meshy AI, post-processed)
│   ├── [AI] Enclosure (OpenSCAD code generated by Claude Code)
│   ├── [AI] Figurine base template (OpenSCAD code generated by Claude Code)
│   └── [ ] Electronics assembly (manual)
└── Software (what runs on the Pi)
    └── [AI] Application code (written with Claude Code)
```

**Content is NOT AI-generated.** Parents curate content from YouTube and download
it to the device via the web UI. The app handles downloading and format conversion.

---

## 1. YouTube Media (parent-curated)

All media comes from YouTube. Parents paste URLs into the web UI and choose whether
to save each item as video or audio-only.

| Attribute | Detail |
|---|---|
| **Source** | YouTube |
| **Download tool** | `yt-dlp` (running on the Pi) |
| **Video format**| MP4 (H.264, up to 1080p) |
| **Audio format**| MP3 (extracted from video, 192kbps) |
| **Thumbnails**  | Auto-downloaded from YouTube metadata |
| **Storage** | `media/video/`, `media/audio/`, `media/thumbnails/`  |

### Download Modes

| Mode | What happens | Use case |
|---|---|---|
| **Video**  | Downloads best MP4 stream (up to 1080p) + audio merged | Cartoons, music videos, shows |
| **Audio**  | Extracts audio track only, converts to MP3 | Songs, lullabies, stories |

### How it works (via web UI)

```
1. Parent pastes a YouTube URL into the Media Library page
2. Selects "Video" or "Audio only"
3. Clicks "Download"
4. Backend calls yt-dlp:
   Video: yt-dlp -f "bv*[height<=1080]+ba" --merge-output-format mp4 \
          --write-thumbnail -o "media/video/%(id)s.%(ext)s" <URL>
   Audio: yt-dlp -x --audio-format mp3 --audio-quality 192K \
          --write-thumbnail -o "media/audio/%(id)s.%(ext)s" <URL>
5. Metadata (title, duration, thumbnail) is auto-populated into SQLite
6. Media appears in the library, ready to assign to a figurine
```

### yt-dlp considerations

- `yt-dlp` must be kept updated (`yt-dlp -U`) as YouTube frequently changes
  its API — a cron job or update button in the web UI handles this
- Downloads run in the background so the web UI stays responsive
- The Pi Zero 2 W is slow — a 3-minute video may take a few minutes to download
  and transcode. Progress is shown in the web UI.
- Storage: a 32 GB SD card holds ~50 hours of 720p video or ~500 hours of MP3 audio

---

## 2. [AI] 3D Figurines

Small 3D-printed characters that the child places on the box. Each figurine
contains an RFID tag and magnets (see SPEC.md section 6).

| Attribute | Detail |
|---|---|
| **Model tool**  | Meshy AI (text/image-to-3D) |
| **Post-process**| Blender (cleanup, magnet cavities, base) |
| **Slicer** | Bambu Studio |
| **Printer** | Bambu Lab P2S |
| **Output** | Physical PETG/PLA figurine, 40-60mm tall |
| **Cost** | Meshy free tier available; ~$0.20 filament per figurine |

### Why Meshy AI?

- Built-in "Add Base" tool — creates a flat bottom for magnet embedding
- Direct "Send to Bambu" integration with Bambu Studio
- Exports STL and 3MF natively
- Blender plugin for post-processing
- Free tier is sufficient for this project's volume

### Workflow

```
1. Generate a reference image (optional but recommended)
   └─ Use Midjourney / DALL-E / Flux:
      "Cute cartoon dinosaur figurine, simple round shapes, bright green,
       front view, white background, 3D render style, no fine details"
   └─ Simple designs = better 3D generation results

2. Generate 3D model in Meshy AI
   └─ Use image-to-3D mode (upload the reference image)
   └─ OR use text-to-3D: "cute simple cartoon bunny figurine, round body,
      big eyes, smooth surface, flat base"
   └─ Generate 2-3 variants, pick the best
   └─ Use Meshy's "Add Base" tool to ensure a flat bottom

3. Post-process in Blender (~10 min per model)
   └─ Import the mesh (STL/OBJ)
   └─ Check manifold: Select > All by Trait > Non-Manifold → fix any issues
   └─ Thicken thin features (ears, limbs) to min 2mm for toddler safety
   └─ Round off any sharp points
   └─ Boolean subtract magnet cavities from the base:
      - 2x cylinders: 6.3mm diameter x 3.2mm deep (6mm magnet + tolerance)
      - Centers 20mm apart (matching box magnets)
   └─ Boolean subtract RFID tag recess:
      - Cylinder: 25.5mm diameter x 0.5mm deep (coin sticker sits flush)
      - Centered in the base
   └─ Verify base is flat, total base thickness >= 5mm
   └─ Export as STL

4. Slice in Bambu Studio
   └─ Import STL, scale to target height (40-60mm)
   └─ Orient flat base down
   └─ Layer height: 0.16mm (good detail vs. speed tradeoff)
   └─ Infill: 15-20% (lightweight but sturdy)
   └─ Material: PETG (stronger) or PLA (easier, more colors)
   └─ Add tree supports for overhangs >45 degrees
   └─ Add pause at layer just above magnet cavities:
      "Pause at layer [N] — insert magnets (check polarity!)"
   └─ Send to printer

5. Assembly (post-print)
   └─ Remove supports, light sanding
   └─ Insert magnets into cavities (verify polarity against box magnets!)
   └─ Seal magnets with a drop of super glue or UV resin
   └─ Stick RFID coin tag into the base recess
   └─ Optional: seal base with a thin 3D-printed cap or sticker

6. Register
   └─ Place figurine on the box
   └─ Open web UI → Figurine Manager → assign to a media file
```

### Figurine Base Template (standardized)

Every figurine shares this base geometry, regardless of what sits on top:

```
     Top view (base underside)            Cross-section
     ┌─────────────────────┐
     │                     │              ┌─────────────────┐
     │  (○)           (○)  │  magnets     │▓▓▓▓▓▓▓▓▓▓▓▓▓▓▓▓▓│ figurine body
     │   6.3mm        6.3mm│              │─────────────────│
     │     ←── 20mm ──→    │              │  ○   [RFID]  ○  │ base (5mm)
     │                     │              │  mag  tag   mag │
     │   ┌─────────────┐   │              └─────────────────┘
     │   │  RFID recess│   │
     │   │   25.5mm    │   │
     │   └─────────────┘   │
     │                     │
     └─────────────────────┘
           35mm wide
```

A Blender template file with the base already modeled (magnet cavities, RFID
recess, correct dimensions) will be created so new figurine tops can simply be
Boolean-unioned onto it.

### Alternative: Tripo3D or Sloyd

| Tool | Strength | Weakness |
|---|---|---|
| Meshy AI  | Bambu integration, "Add Base" tool | Some meshes need cleanup |
| Tripo3D | Fastest generation, clean topology | No native "add base" feature |
| Sloyd | "3D Print" preset = watertight meshes  | Less detail on characters |

---

## 3. [AI] Enclosure & Figurine Base (OpenSCAD)

The enclosure and figurine base template are parametric OpenSCAD scripts generated
by Claude Code. OpenSCAD is a code-based CAD tool — geometry is defined by writing
scripts, which makes it a natural fit for AI generation.

| Attribute | Detail |
|---|---|
| **Design tool** | Claude Code → OpenSCAD `.scad` files |
| **Renderer** | OpenSCAD (renders `.scad` → STL) |
| **Slicer** | Bambu Studio |
| **Printer** | Bambu Lab P2S |
| **Material** | PETG |

### Files generated

| File | What it defines |
|---|---|
| `babybox-case-v3.scad`  | **Current.** Compact case (90x90, body ~47mm): 3 parts (tray / body / top plate) + sealed diffuser ring. Recessed figurine hole with the LED ring + flush RFID; soldered build, heat-set inserts, MX buttons, tiny power-cable hole. `render_part` selects the part |
| `keycaps.scad` | Big round custom MX keycaps (play/pause + stop) with engraved icons |
| `common-params.scad` | Shared dims: magnets, RFID, MFRC522, screws, **+ v3: heat-set inserts, WS2812B strip, MX switch/keycap** |
| `babybox-case-v2.scad`  | v2 (reference). Compact "Pebble" face case (105x85x54), body + lid in one file |
| `babybox-case.scad` | v1 (reference). Main box body: walls, button holes, LED slot, port cutouts, internal mounts |
| `base-template.scad` | Standard figurine base: magnet cavities, RFID recess, flat bottom (unchanged — works with v3) |

### Why OpenSCAD + Claude Code?

- **Code = AI-friendly:** OpenSCAD scripts are just code — Claude Code writes them
  the same way it writes Python
- **Parametric:** All dimensions are variables at the top of the file. Change
  `wall_thickness = 3;` to `4` and re-render — everything adjusts automatically
- **Reproducible:** No manual mouse-driven modeling. The exact geometry is in the
  script and version-controlled in git
- **Iterative:** Easy to ask Claude Code to "make the button holes 2mm bigger" or
  "add ventilation slots" — it edits the script and you re-render

### Workflow

```
1. Claude Code generates the .scad files based on SPEC.md dimensions
   └─ Enclosure: 120x90x60mm, 3mm walls, rounded corners
   └─ All component positions parameterized (GPIO header, MFRC522, etc.)

2. Open in OpenSCAD and preview (F5)
   └─ Visual check: does it look right?
   └─ Cross-section view to check internal mounts and cavities

3. Iterate with Claude Code
   └─ "The HDMI cutout is 2mm too low" → edit the script → re-preview
   └─ Repeat until satisfied

4. Render (F6) and export STL

5. Import STL into Bambu Studio
   └─ Slice with PETG profile
   └─ Print
```

### Figurine base template usage

The `base-template.scad` file defines the standard base that all figurines share.
To make a new figurine:

```
1. Generate figurine top in Meshy AI (animal, vehicle, character)
2. Export as STL
3. In Blender:
   └─ Import the Meshy STL (figurine top)
   └─ Import the base-template STL (rendered from OpenSCAD)
   └─ Align and Boolean union them
   └─ Export combined STL
4. Slice and print in Bambu Studio
```

See SPEC.md section 7 for full enclosure design requirements.

---

## 4. [AI] Application Software

All Python code for the BabyBox is written with AI assistance (Claude Code).

| Attribute | Detail |
|---|---|
| **Tool** | Claude Code (Claude Opus) |
| **Language** | Python 3 |
| **Output** | Source files in `software/` |
| **Review** | All code reviewed and tested by the developer |

### What AI generates

- Core controller, RFID listener, media player wrapper, LED/buzzer drivers
- YouTube downloader (`yt-dlp` wrapper with format selection)
- SQLite database layer and data models
- Flask web UI (backend routes + HTML/CSS/JS templates)
- Bluetooth connection management
- systemd service files and setup scripts

### What stays manual

- GPIO pin testing and hardware debugging
- Bluetooth pairing troubleshooting
- System-level configuration (raspi-config, SPI enable, etc.)
- Final integration testing on the physical Pi

---

## Summary: Tool Stack

| Artifact | Tool | AI?  | Output Format |
|---|---|---|---|
| Videos for playback  | YouTube + yt-dlp | No | MP4 |
| Audio for playback | YouTube + yt-dlp | No | MP3 |
| Enclosure CAD | Claude Code → OpenSCAD | Yes | .scad → STL |
| Figurine base template | Claude Code → OpenSCAD | Yes | .scad → STL |
| Figurine 3D models | Meshy AI | Yes  | STL |
| Figurine post-process| Blender | No | STL |
| Figurine reference images | Midjourney / DALL-E | Yes | PNG |
| Application code | Claude Code | Yes  | Python / HTML |

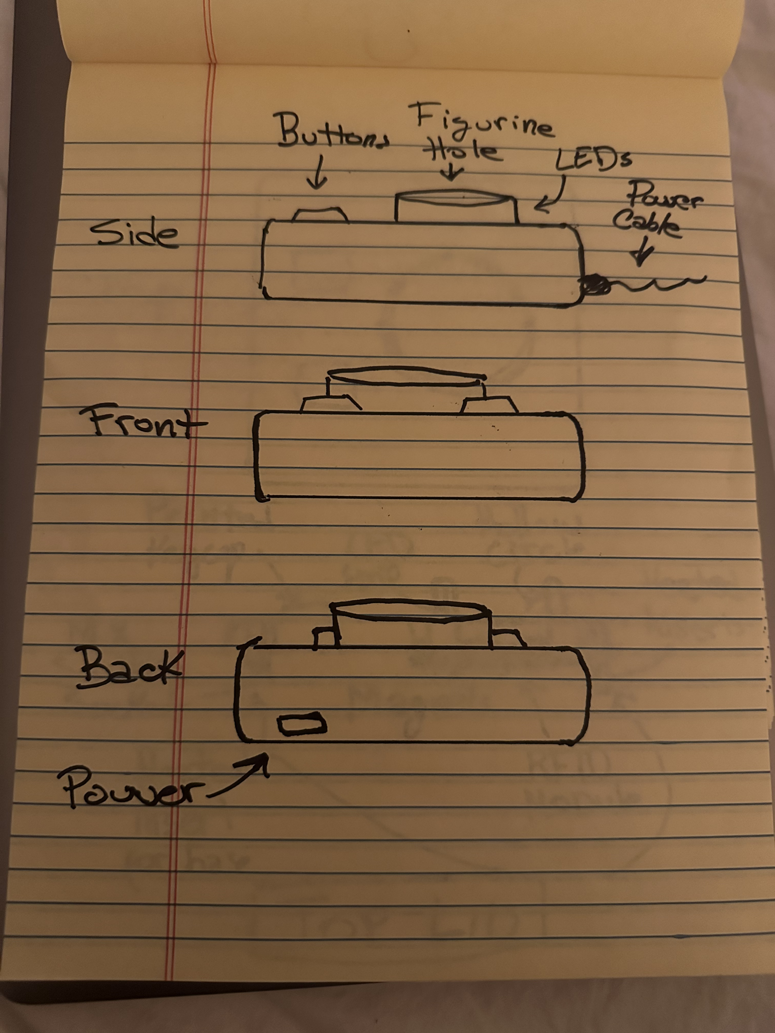
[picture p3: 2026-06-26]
hardware/sketches/sketch-side-front-back.jpeg

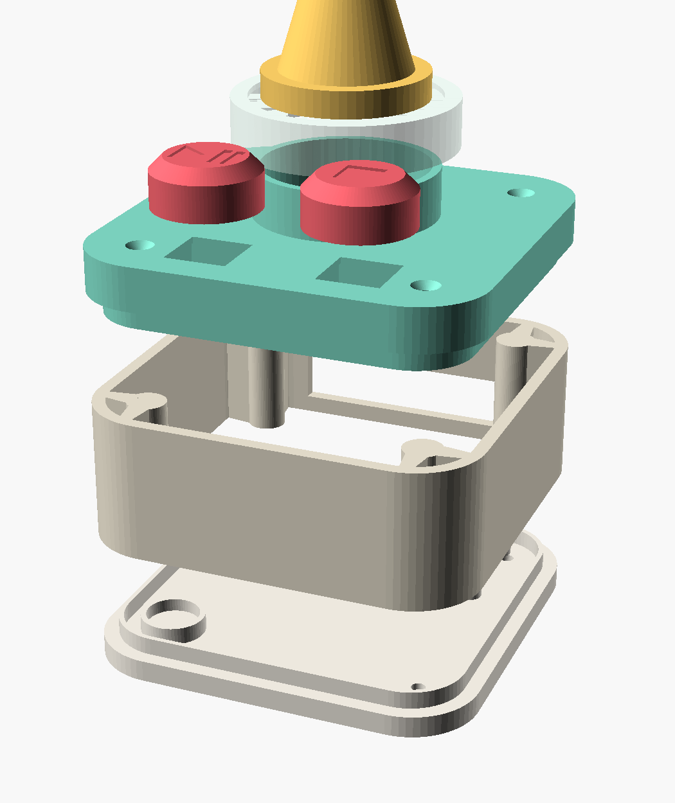
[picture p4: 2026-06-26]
website/images/v3-exploded.png

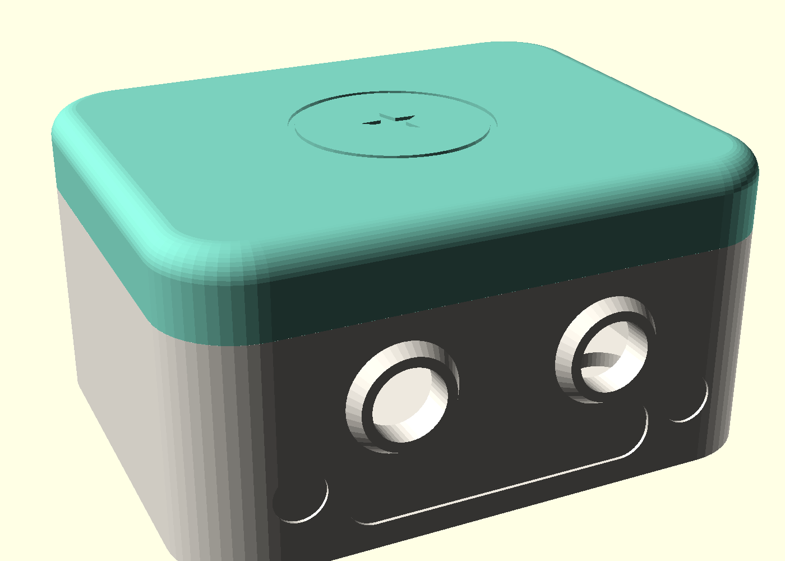
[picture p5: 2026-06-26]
renders/v2-hero.png

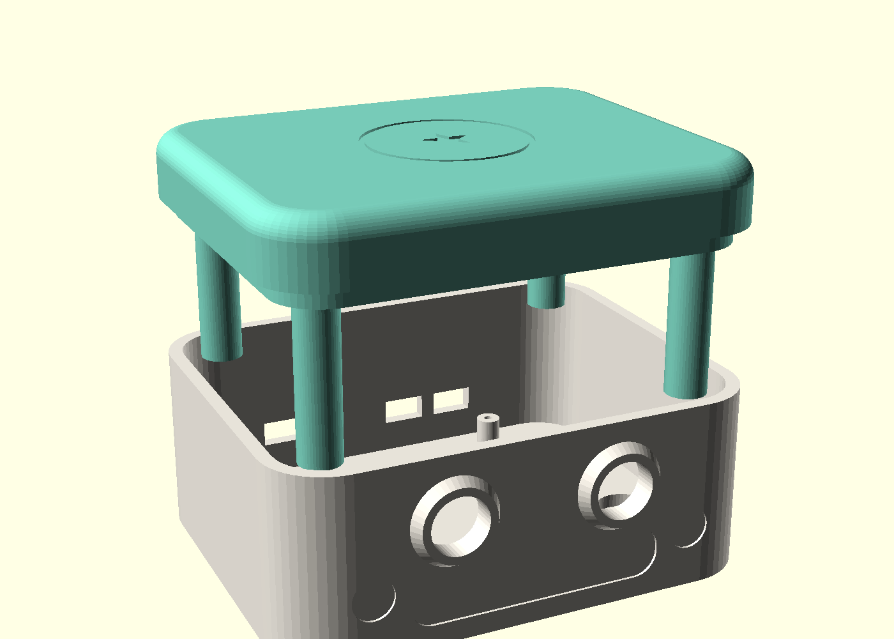
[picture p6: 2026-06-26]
renders/v2-exploded.png

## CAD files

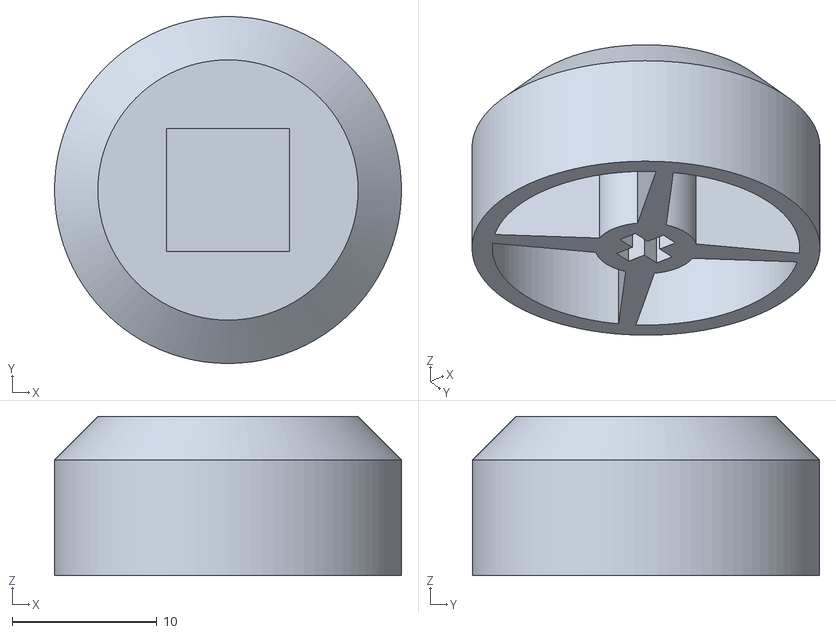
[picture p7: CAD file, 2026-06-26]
renders/v3-keycap-stop.stl
24.0 x 24.0 x 11.0

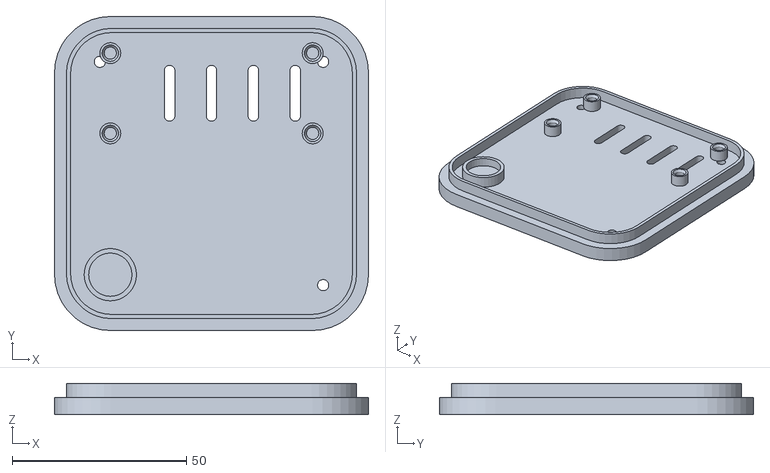
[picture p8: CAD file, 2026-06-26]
website/models/v3-tray.stl
90.0 x 90.0 x 9.00

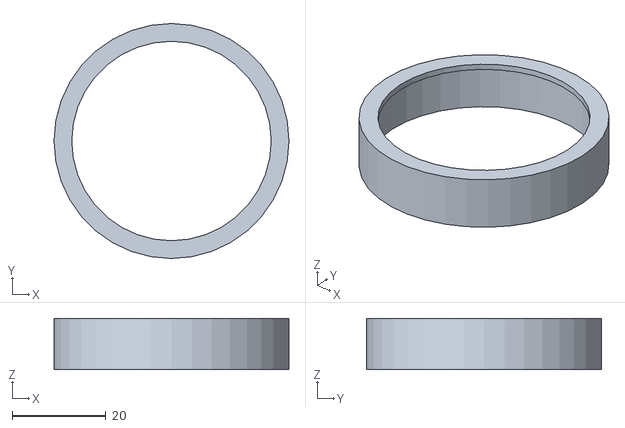
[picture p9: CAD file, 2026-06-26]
website/models/v3-diffuser.stl
50.2 x 50.2 x 11.0

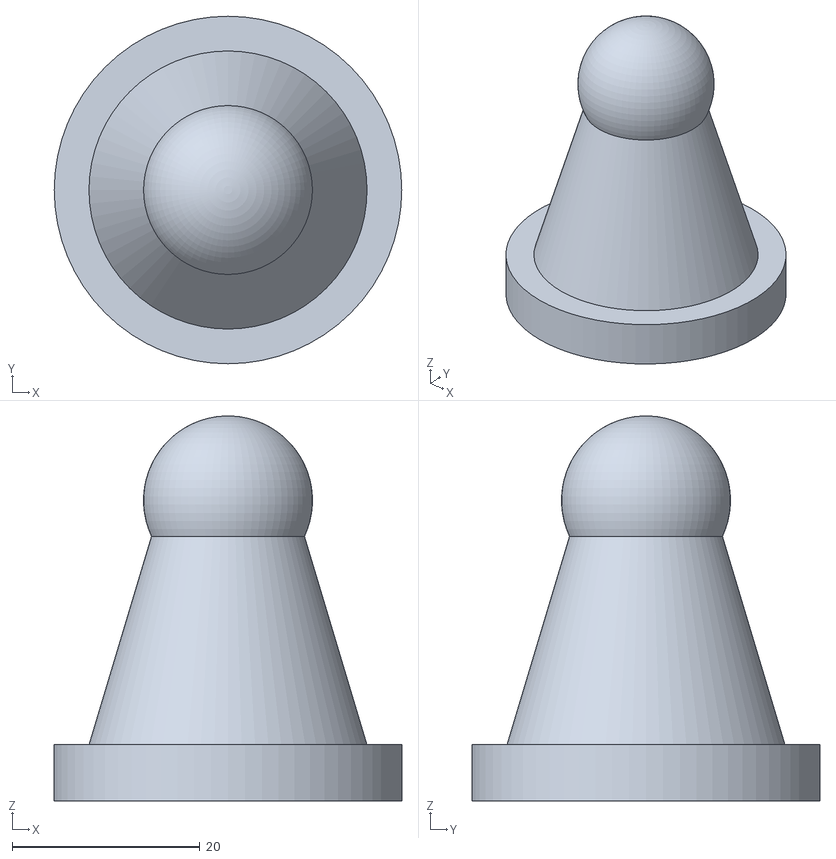
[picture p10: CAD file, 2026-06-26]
renders/v3-figurine.stl
37.0 x 37.0 x 41.0

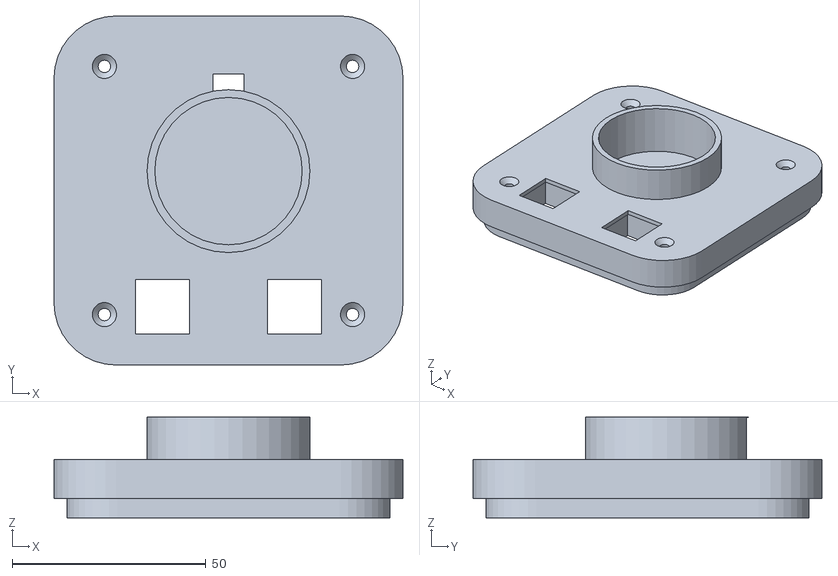
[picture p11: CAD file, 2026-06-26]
website/models/v3-top.stl
90.0 x 90.0 x 26.0

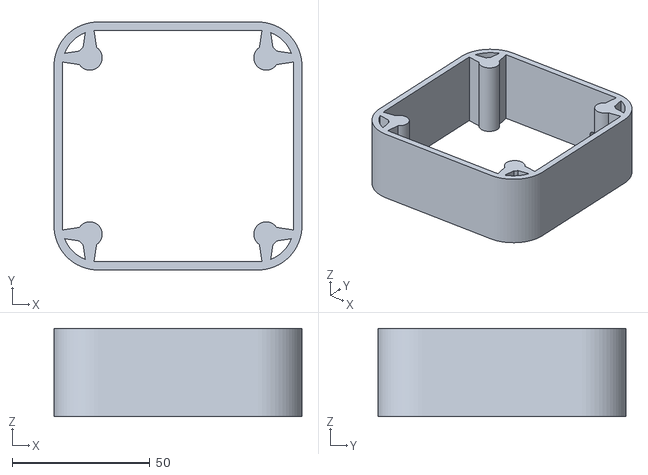
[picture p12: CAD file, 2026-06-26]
renders/v3-body.stl
90.0 x 90.0 x 32.0

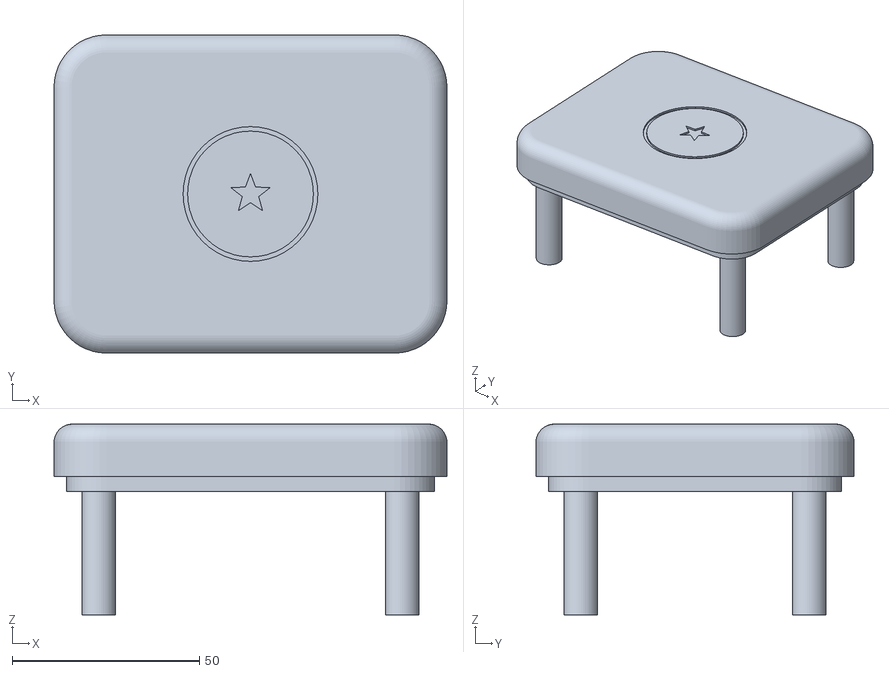
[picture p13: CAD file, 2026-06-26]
renders/v2-lid.stl
105.0 x 85.0 x 51.0

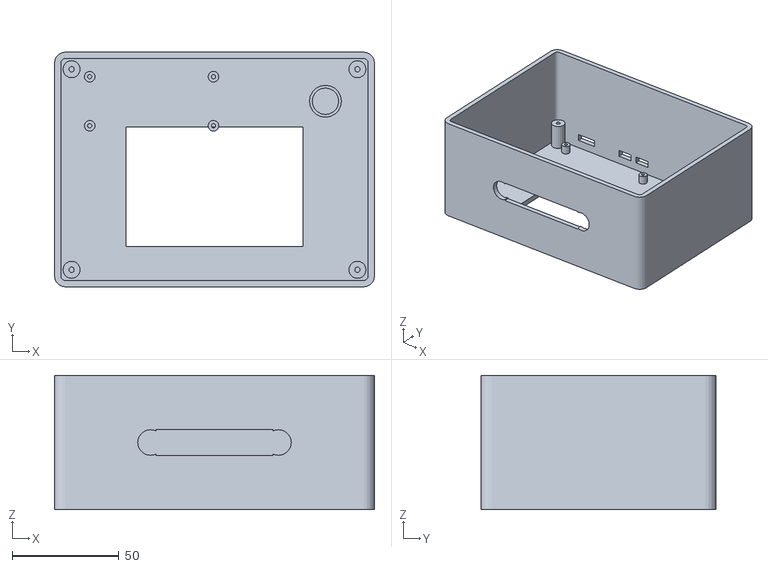
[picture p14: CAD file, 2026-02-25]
renders/body.stl
150.0 x 110.0 x 63.0

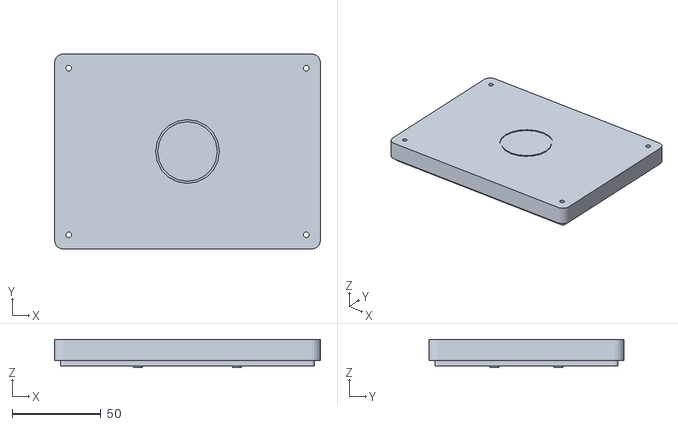
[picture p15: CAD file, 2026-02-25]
renders/lid.stl
150.0 x 110.0 x 16.0

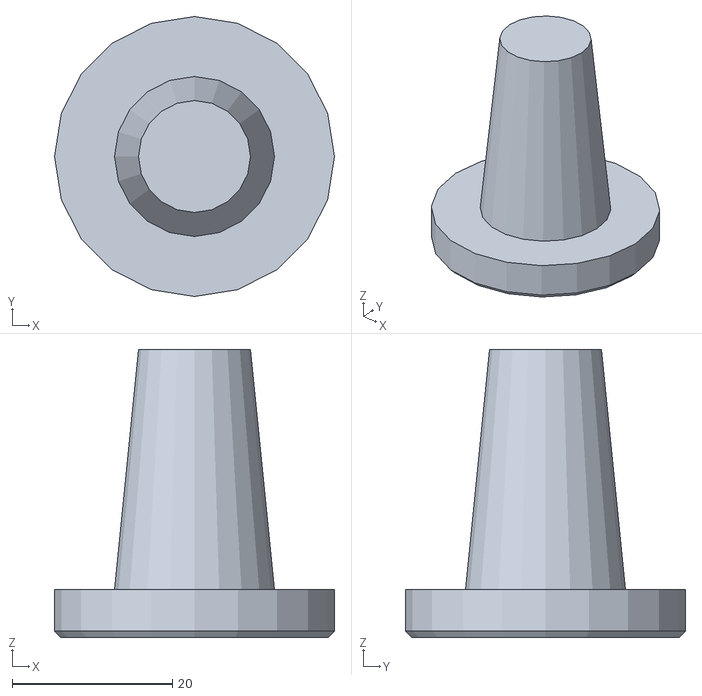
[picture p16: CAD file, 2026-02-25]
renders/figurine.stl
35.0 x 35.0 x 36.0

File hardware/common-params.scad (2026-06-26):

// common-params.scad — Shared dimensions for BabyBox enclosure + figurines
// All values in millimeters

// === Neodymium Magnets (6x3mm disc) ===
magnet_dia       = 6;      // nominal diameter
magnet_h         = 3;      // nominal height
magnet_pocket_dia = 6.3;   // pocket diameter (0.3mm clearance for drop-in)
magnet_pocket_h  = 3.2;    // cavity height (0.2mm extra so magnet sits below rim)
magnet_spacing   = 20;     // center-to-center distance between the two magnets
magnet_seal_h    = 1.0;    // solid wall thickness enclosing magnets on each side
                            // (pause print, insert magnets, resume to seal)

// === RFID Sticker Tag (25mm coin, MIFARE 13.56 MHz) ===
rfid_tag_dia     = 25;     // nominal diameter
rfid_tag_h       = 0.3;    // sticker thickness (very thin)
rfid_recess_dia  = 25.5;   // recess diameter (0.5mm tolerance)
rfid_recess_h    = 0.5;    // recess depth

// === MFRC522 RFID Module ===
mfrc522_l        = 60;     // board length
mfrc522_w        = 40;     // board width
mfrc522_h        = 4;      // PCB thickness (without header)
mfrc522_h_header = 8;      // total height with header pins
mfrc522_hole_dia = 2;      // mounting hole diameter (M2)
mfrc522_hole_x   = 56;     // mounting hole X spacing
mfrc522_hole_y   = 36;     // mounting hole Y spacing
mfrc522_hole_margin_x = 2; // hole inset from board edge X
mfrc522_hole_margin_y = 2; // hole inset from board edge Y

// === Print Tolerances ===
tol              = 0.3;    // general clearance tolerance
press_tol        = 0.15;   // press-fit tolerance (tighter)
wall_min         = 1.2;    // minimum printable wall thickness (3 perimeters at 0.4mm)

// === Screw Dimensions ===
m2_hole_dia      = 2.2;    // M2 clearance hole
m2_tap_dia       = 1.6;    // M2 self-tap hole in plastic
m25_hole_dia     = 2.7;    // M2.5 clearance hole
m25_tap_dia      = 2.0;    // M2.5 self-tap hole in plastic
m3_hole_dia      = 3.2;    // M3 clearance hole
m3_tap_dia       = 2.5;    // M3 self-tap hole in plastic

// ===================================================================
//  v3 "Tower" additions
// ===================================================================

// === Brass heat-set inserts (threaded inserts melted into plastic) ===
// The v3 build uses heat-set inserts everywhere instead of self-tapping,
// so the box can be opened and re-assembled many times. Default values are
// for the very common McMaster/CNC-Kitchen style tapered inserts. Tune the
// *_hole_dia to your specific inserts if needed (a touch tight is better —
// the melted brass swages into the wall).
//
// M3 insert (standard, body<->tray + top plate)
m3_insert_hole_dia = 4.0;   // pilot hole the insert melts into
m3_insert_h        = 5.0;   // insert length (boss must be deeper)
m3_insert_boss_od  = 6.5;   // outer diameter of the boss around the insert
// M2.5 insert (Pi Zero 2 W mounting)
m25_insert_hole_dia = 3.5;
m25_insert_h        = 4.0;
m25_insert_boss_od  = 5.5;
// M2 insert (MFRC522 mounting)
m2_insert_hole_dia  = 3.2;
m2_insert_h         = 3.5;
m2_insert_boss_od   = 5.0;

// === SunFounder WS2812B flexible strip (the LED "halo" ring) ===
// 8x 5050 RGB LEDs, 60 pixels/m -> 16.67 mm pitch, flexible & cuttable.
// Bent into a circle the lit length wraps to a centerline circle:
//   circumference = pitch * count  ->  dia = (pitch*count)/PI
led_count        = 8;
led_pitch        = 16.67;   // mm between LEDs (60/m)
led_strip_w      = 10.0;    // strip width  (standard 5050 flex strip)
led_strip_t      = 2.0;     // strip thickness (datasheet: 2 mm)
led_strip_fit    = 0.6;     // clearance added to width/thickness for the channel
// Centerline diameter when the strip is curled into a ring.
led_ring_mid_dia = (led_pitch * led_count) / PI;     // ~42.4 mm
led_lead_w       = 8;       // notch width for the 3-wire pigtail to drop through

// === Cherry MX (compatible) keyswitches + custom keycaps ===
// Plate-mount MX switch: 14x14 mm plate cutout, clips grab a ~1.5 mm plate.
mx_switch_cut    = 14.0;    // square hole in the plate (top-of-plate)
mx_switch_body   = 15.6;    // switch top housing footprint (sits ON the plate)
mx_plate_t       = 1.5;     // plate thickness the switch clips engage
mx_switch_below  = 5.0;     // body depth below the plate (to the pins start)
mx_switch_pins_h = 3.3;     // pin/leg protrusion below the body
mx_keycap_pitch  = 19.05;   // 1u spacing (center-to-center of adjacent caps)
// v3 uses BIG ROUND toddler keycaps instead of square 1u caps
mx_keycap_round_dia = 24;   // chunky circular button cap
mx_keycap_round_h   = 11;   // cap height above the plate (domed)
// MX stem (the + cross on the switch the keycap presses onto)
mx_stem_cross_w  = 4.1;     // length of each arm of the + (outer span)
mx_stem_arm_t    = 1.35;    // thickness of each arm (1.17 nominal + fit)
mx_stem_depth    = 4.0;     // how deep the cross socket goes into the cap

function led_ring_id() = led_ring_mid_dia - led_strip_t - led_strip_fit;  // inner wall sits here
function led_ring_od() = led_ring_mid_dia + led_strip_t + led_strip_fit;  // outer wall sits here

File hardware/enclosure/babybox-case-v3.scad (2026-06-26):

// babybox-case-v3.scad — "Tower" enclosure, rev C (recessed figurine well)
//
// Redrawn from the paper sketches in hardware/sketches/ and refined from
// feedback. The top is a RAISED, SEALED LED ring with a RECESSED HOLE in the
// middle: the figurine drops straight down into the hole and sits nested,
// ringed by the glow. The MFRC522 sits flush right under the thin hole floor
// (a few mm from the tag) so it reads reliably. No raised lid, no exposed
// LED strip, and the body is only as tall as the electronics need.
//
//   ┌─ figurine drops into the hole, sits recessed ─────────┐
//   │   ● RAISED LED RING (sealed): flexible WS2812B strip   │
//   │     wrapped around the hole wall, fully covered by a   │
//   │     glued translucent diffuser cap — nothing to pick   │
//   │   ● RECESSED HOLE: figurine well, magnets in the floor │
//   │   ● MFRC522 mounts FLUSH under the hole floor (~5 mm)  │
//   │   ● 2x MX buttons with big round keycaps, in front     │
//   │   ● short BODY tube; Pi Zero 2 W + buzzer on the TRAY  │
//   └────────────────────────────────────────────────────────┘
//
// SOLDERED build, no breadboard. HEAT-SET inserts everywhere. Four corner
// columns run the body height with an insert at each end (tray bolts up,
// top plate bolts down).
//
// PRINTING (all parts, no supports):
//   * TRAY      — flat on the bed
//   * BODY      — one open end on the bed
//   * TOP PLATE — print RIGHT-SIDE UP (underside on the bed): the raised ring
//                 prints up, the figurine hole is a clean recess, the RFID
//                 insert holes drill up from the underside. PAUSE at the
//                 echoed Z to drop the 2 ring magnets, then resume.
//   * DIFFUSER  — translucent/natural; glued over the strip to seal the ring
//   * KEYCAPS   — see keycaps.scad
//
// Render: set render_part, F5 to preview, F6 + export STL.

include <../common-params.scad>
use <keycaps.scad>      // big round keycaps (modules only, for the assembly view)

// === Render Selector ===
// "body" | "tray" | "top" | "diffuser" | "assembly" | "exploded"
render_part = "assembly";

// Underside logo on the tray — disable (-D show_logo=false) for lighter
// web/preview STL exports; the text is heavy and faces the table anyway.
show_logo = true;
// Show a stand-in figurine seated in the hole (assembly/exploded views only).
show_figurine = true;

$fn = 64;

// ──────────────────────────────────────────────────
// Master dimensions
// ──────────────────────────────────────────────────
box_l    = 90;     // outer footprint X
box_w    = 90;     // outer footprint Y  (square; deep enough that the RFID
                   //   board clears the rear corner columns)
wall     = 3;      // side wall thickness
corner_r = 16;     // XY corner radius (toddler-safe, toy look)

body_h       = 32;   // main tube height — only as tall as the Pi + wiring need
tray_h       = 5;    // bottom tray plate thickness
tray_lip_h   = 4;    // tray centering spigot up into the body
top_plate_h  = 10;   // top plate slab thickness
top_lip_h    = 5;    // top plate centering spigot down into the body
clr          = 0.4;  // nesting clearance

inner_l = box_l - 2*wall;   // 78
inner_w = box_w - 2*wall;   // 78
cx = box_l/2;  cy = box_w/2;

// === Corner columns (full-height, heat-set insert at each end) ===
col_od    = 9;
col_inset = 13;
col_pos = [
    [col_inset,          col_inset],
    [box_l - col_inset,  col_inset],
    [col_inset,          box_w - col_inset],
    [box_l - col_inset,  box_w - col_inset],
];

// === Back power hole ===
// The SMALLEST sensible opening: a little rounded RECTANGLE lined up EXACTLY
// with the Pi's micro-USB *power* port. No HDMI/USB-data is exposed — the box
// is otherwise fully closed (baby-safe). The Pi sits at the back with its
// connector edge facing this wall; the power port is the rightmost of the
// three connectors (~54 mm along the board from the SD-card end).
pi_pwr_off = 54.0;             // power-port center, from the board's left edge
pwr_hole_w = 11;              // width  (clears a micro-USB plug)
pwr_hole_h = 6;               // height (too shallow to admit a finger)
pwr_hole_r = 1.5;             // rounded corners — no sharp edges
// position is derived from the Pi below (pwr_hole_cx, pwr_hole_z)

// === Pi Zero 2 W on the tray ===
pi_l = 65;  pi_w = 30;
pi_hole_x_spacing = 58;
pi_hole_y_spacing = 23;
pi_hole_inset     = 3.5;
pi_standoff_h     = 4;
pi_standoff_od    = 6;
pi_x = (box_l - pi_l)/2;
pi_y = box_w - wall - pi_w - 4;   // connector edge (+Y) faces the back wall

// power hole lines up with the Pi's micro-USB power port (derived)
pwr_hole_cx = pi_x + pi_pwr_off;              // X of the power port
pwr_hole_z  = pi_standoff_h + 3;              // ~ micro-USB center above the tray

// === Buzzer cradle (on the tray) ===
buzzer_dia      = 12;
buzzer_mount_od = 15;
buzzer_mount_h  = 4;
buzzer_x = 16;  buzzer_y = 16;

// === RAISED LED ring + RECESSED figurine hole ===========================
hub_cx     = cx;
hub_cy     = cy + 5;             // ring/hole sits toward the back
well_dia   = 38;                 // the hole the figurine drops into
well_depth = 5;                  // recess into the plate (figurine nests here)
well_floor = top_plate_h - well_depth;   // 5 mm of floor under the figurine
well_wall  = 2;                  // wall between the hole and the strip
ring_h     = led_strip_w + 1;    // how far the sealed ring stands proud (11)

// strip wraps the OUTSIDE of the hole wall; LEDs face out into the diffuser
strip_wrap_r = well_dia/2 + well_wall;          // 21 -> wrap dia 42 (= strip len/pi)
strip_out_r  = strip_wrap_r + led_strip_t;      // 23
diff_ir      = strip_out_r + 0.3;               // 23.3 (clears the strip)
diff_wall    = 1.8;
diff_or      = diff_ir + diff_wall;             // 25.1 (glowing outer face)
diff_flange  = 1.2;                             // top cap thickness over the strip
strip_notch_w = led_lead_w;                     // wire pass-through at the ring base

// magnets in the hole floor (snap + align the figurine). Printed right-side
// up, the pockets seal when the print reaches this Z — pause and drop them in.
ring_magnet_pause_z = magnet_seal_h + magnet_pocket_h;   // = 4.2 mm

// === RFID flush under the hole floor (antenna up, ~5 mm to the tag) ===
rfid_pocket_clr = 1.0;          // around the board, so it locates flush

// === MX-switch buttons ===
btn_spacing = 34;
btn_y       = 15;
btn1_x = cx - btn_spacing/2;
btn2_x = cx + btn_spacing/2;

// === Bottom-of-tray details ===
bumper_dia   = 11;  bumper_depth = 0.5;
bumper_pos   = [[16,16],[box_l-16,16],[16,box_w-16],[box_l-16,box_w-16]];
vent_w = 3;  vent_l = 16;
vent_x = [33,45,57,69];  vent_y = 60;   // under the Pi (which sits at the back)

// ──────────────────────────────────────────────────
// Sanity
// ──────────────────────────────────────────────────
echo(str(">>> BabyBox v3 rev C: ", box_l, " x ", box_w,
         " x ", tray_h + body_h + top_plate_h, " mm body (ring +",
         ring_h, " mm, figurine on top)"));
echo(str(">>> LED strip wraps dia ", 2*strip_wrap_r,
         " mm (strip length ~", led_pitch*led_count, " mm)."));
echo(str(">>> TOP PLATE: print right-side up, PAUSE at Z = ",
         ring_magnet_pause_z, " mm, drop 2x 6x3 magnets, resume."));

assert(pi_x + pi_l <= box_l - wall, "Pi too long for footprint");
assert(pi_y >= wall && pi_y + pi_w <= box_w - wall, "Pi doesn't fit in Y");
assert(well_floor >= magnet_seal_h + magnet_pocket_h, "hole floor too thin for magnets");
assert(mfrc522_l <= inner_l && mfrc522_w <= inner_w, "MFRC522 won't fit inside");
// big round keycaps clear the raised ring and each other
assert(sqrt(pow(btn2_x - hub_cx, 2) + pow(btn_y - hub_cy, 2))
       - mx_keycap_round_dia/2 - diff_or >= 0.5, "round caps overlap the LED ring");
assert(btn_spacing - mx_keycap_round_dia >= 4, "round caps collide");
// RFID board must clear the back wall and the corner columns
assert(hub_cy + mfrc522_w/2 <= box_w - wall - 0.5, "RFID board hits back wall");
rfid_holes = [for (sx = [-1,1], sy = [-1,1])
              [hub_cx + sx*mfrc522_hole_x/2, hub_cy + sy*mfrc522_hole_y/2]];
assert(min([for (h = rfid_holes) for (c = col_pos) norm([h.x-c.x, h.y-c.y])]) >= 5,
       "RFID mount holes collide with the corner columns");
// body must be tall enough for the Pi to clear the flush RFID under the lid
assert(body_h >= pi_standoff_h + 12 + 4, "body too short for the Pi stack");
// power hole sits over the Pi board and on the flat part of the back wall
assert(pwr_hole_cx - pwr_hole_w/2 >= pi_x && pwr_hole_cx + pwr_hole_w/2 <= pi_x + pi_l,
       "power hole not over the Pi board");
assert(pwr_hole_cx + pwr_hole_w/2 <= box_l - corner_r - 1,
       "power hole runs into the rounded corner");
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

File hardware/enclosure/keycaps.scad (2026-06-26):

// keycaps.scad — Big round custom keycaps for the BabyBox v3 "Tower"
//
// NOT standard square 1u caps — these are chunky CIRCULAR buttons sized for
// toddler fingers, that press straight onto a Cherry-MX (compatible) switch
// stem. Two caps: PLAY/PAUSE (triangle + bars) and STOP (square), each with
// the icon engraved 0.6 mm into the domed top so it survives sticky hands.
//
// PRINTING: print TOP-DOWN (flat top on the bed). The chamfered top lands
// flat, the hollow underside and the + stem socket print cleanly with no
// supports. For a two-tone icon, do a filament swap at the engrave depth,
// or just print solid and the recessed icon reads fine on its own.
//
// FIT NOTE: the + socket is sized for a 0.15 mm press-fit. If your caps are
// loose, drop mx_stem_arm_t by 0.05; if they won't seat, raise it by 0.05.
//
// Render: set render_part, F5 preview, F6 + export STL.

include <../common-params.scad>

// "play" | "stop" | "both"
render_part = "both";

$fn = 96;

cap_d     = mx_keycap_round_dia;    // 24 — big round button
cap_h     = mx_keycap_round_h;      // 11
top_cham  = 3.0;                    // rounded-looking top chamfer
wall      = 1.4;                    // skirt wall
top_th    = 2.6;                    // solid roof under the icon
boss_od   = 7.0;                    // stem mount boss
icon_depth = 0.6;

// ──────────────────────────────────────────────────
// Cap shell + stem
// ──────────────────────────────────────────────────
module cap_blank() {
    // round puck with a chamfered top edge (prints flat-top-down)
    rotate_extrude()
        polygon([
            [0, 0],
            [cap_d/2, 0],
            [cap_d/2, cap_h - top_cham],
            [cap_d/2 - top_cham, cap_h],
            [0, cap_h],
        ]);
}

module mx_stem_socket() {
    // the + cross the switch stem presses into (a press-fit negative)
    linear_extrude(mx_stem_depth + 0.05) {
        square([mx_stem_cross_w, mx_stem_arm_t], center = true);
        square([mx_stem_arm_t, mx_stem_cross_w], center = true);
    }
}

module stem_mount() {
    // boss bridging the cap roof down to the switch stem
    difference() {
        cylinder(d = boss_od, h = cap_h - top_th);
        translate([0, 0, -0.01]) mx_stem_socket();
    }
    // four little ribs tying the boss to the skirt so the cap can't twist
    for (a = [45, 135, 225, 315])
        rotate([0, 0, a])
            translate([0, 0, 0])
                linear_extrude(cap_h - top_th)
                    polygon([[boss_od/2 - 0.2, -1], [cap_d/2 - wall, -0.6],
                             [cap_d/2 - wall, 0.6], [boss_od/2 - 0.2, 1]]);
}

// ──────────────────────────────────────────────────
// Icons (engraved into the top)
// ──────────────────────────────────────────────────
module icon_play_pause() {
    translate([-3.7, 0]) polygon([[-3, -4.5], [-3, 4.5], [3.6, 0]]);  // play ▶
    translate([3.2, 0]) square([1.9, 9], center = true);             // ❚
    translate([6.1, 0]) square([1.9, 9], center = true);             //  ❚
}
module icon_stop() { square([8.5, 8.5], center = true); }            // ■

// The skirt cavity is cut FIRST, then the stem boss/ribs are added back, so
// the boss survives (it lives inside the hollow).
module keycap_final(which) {
    union() {
        difference() {
            cap_blank();
            translate([0, 0, -0.01])
                cylinder(d = cap_d - 2*wall, h = cap_h - top_th + 0.01);
            translate([0, 0, cap_h - icon_depth])
                linear_extrude(icon_depth + 0.05)
                    if (which == "play") icon_play_pause(); else icon_stop();
        }
        stem_mount();
    }
}

if      (render_part == "play") keycap_final("play");
else if (render_part == "stop") keycap_final("stop");
else {
    translate([-cap_d/2 - 3, 0, 0]) keycap_final("play");
    translate([ cap_d/2 + 3, 0, 0]) keycap_final("stop");
}

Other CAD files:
renders/v3-tray.stl
website/models/v3-figurine.stl
renders/v3-keycap-play.stl
website/models/v3-body.stl
renders/v3-top.stl
website/models/v3-keycap-play.stl
renders/v3-diffuser.stl
website/models/v3-keycap-stop.stl
hardware/figurines/base-template.scad
hardware/enclosure/babybox-case-v2.scad
hardware/enclosure/babybox-case.scad
renders/v2-body.stl

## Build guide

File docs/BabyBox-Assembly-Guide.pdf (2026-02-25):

# BabyBox

## Assembly Guide

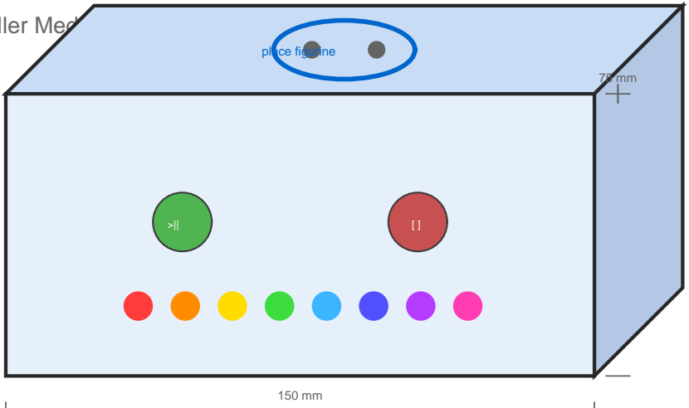
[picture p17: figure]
place figurine

Toddler Media Player | Raspberry Pi Zero 2 W + RFID + 3D Printing

Generated 2026-02-24

# Table of Contents

BabyBox Assembly Guide

# 1. Bill of Materials

Everything you need to build a BabyBox. Most electronic components come from a standard sensor kit. The total cost is approximately $51 if you already own a Bluetooth speaker.

Component | Qty | Source | Est. Cost
Raspberry Pi Zero 2 W | 1 | Purchase | ~$15
MicroSD card (32 GB+) | 1 | Purchase | ~$8
MFRC522 RFID Module | 1 | Sensor kit | --
RFID coin stickers (25mm, 13.56 MHz) | 10 | Purchase | ~$5
Neodymium magnets (6x3mm disc) | 20+ | Purchase | ~$5
Bluetooth speaker | 1 | Already owned | ~$0-20
WS2812 RGB 8-LED strip | 1 | Sensor kit | --
Passive buzzer | 1 | Sensor kit | --
Tactile buttons (6x6mm) | 2 | Sensor kit | --
Resistors / wires / breadboard | 1 | Sensor kit | --
5 V 3 A micro-USB power supply | 1 | Purchase | ~$8
Mini-HDMI to HDMI cable | 1 | Purchase | ~$5
3D-printed enclosure + figurines | 1 | Bambu Lab P2S | ~$5 filament

NOTE: Magnets must be 6 x 3 mm neodymium discs. Larger magnets will not fit the printed pockets. Buy extras -- you need at least 4 per figurine (2 for the figurine base + 2 for the lid) plus spares for polarity mistakes.

# 2. GPIO Wiring Reference

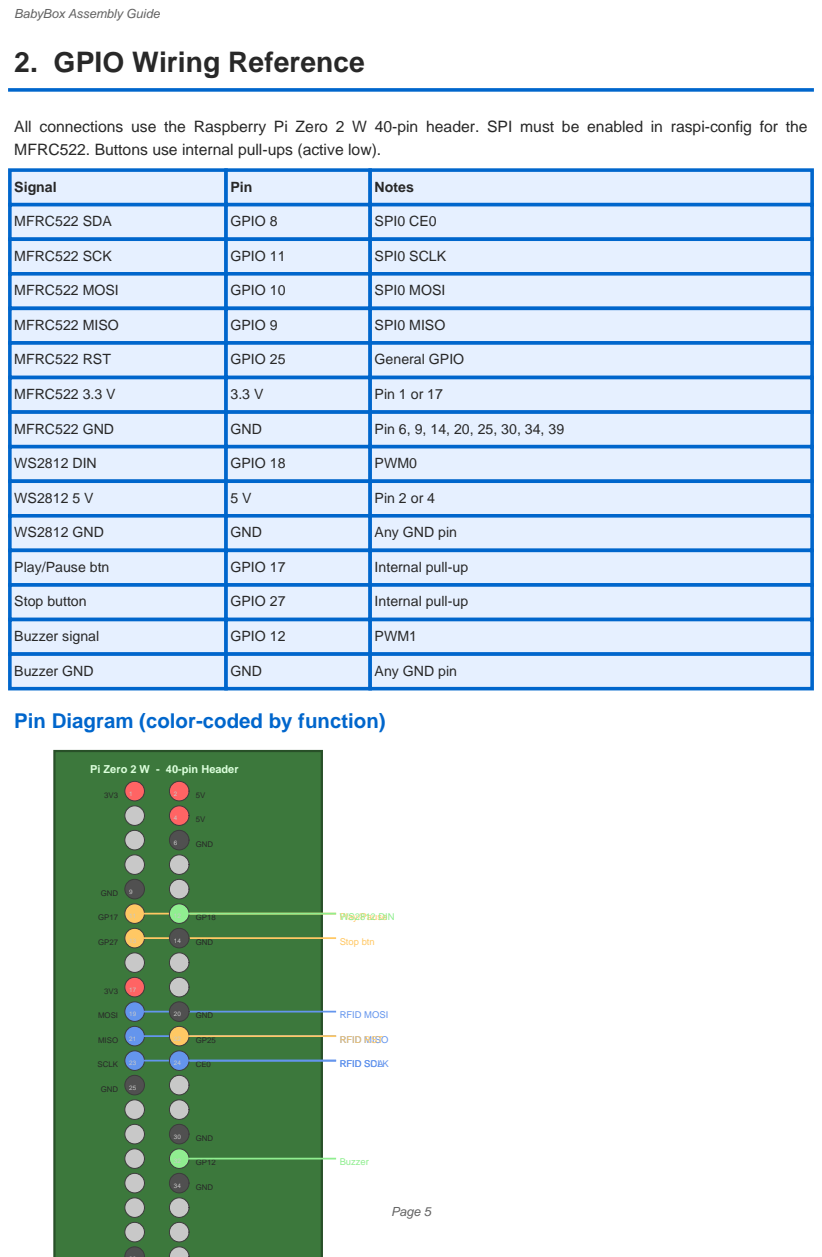
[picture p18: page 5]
GND; Play/Pause WS2812 DIN; Stop btn; MOSI; RFID MOSI ²⁰; MISO; RFID MISO RFID RST; SCLK; RFID SCLK RFID SDA; Buzzer

All connections use the Raspberry Pi Zero 2 W 40-pin header. SPI must be enabled in raspi-config for the
MFRC522. Buttons use internal pull-ups (active low).

Signal | Pin | Notes

MFRC522 SDA | GPIO 8 | SPI0 CE0

MFRC522 SCK | GPIO 11 | SPI0 SCLK

MFRC522 MOSI | GPIO 10 | SPI0 MOSI

MFRC522 MISO | GPIO 9 | SPI0 MISO

MFRC522 RST | GPIO 25 | General GPIO

MFRC522 3.3 V | 3.3 V | Pin 1 or 17

MFRC522 GND | GND | Pin 6, 9, 14, 20, 25, 30, 34, 39

WS2812 DIN | GPIO 18 | PWM0

WS2812 5 V | 5 V | Pin 2 or 4

WS2812 GND | GND | Any GND pin

Play/Pause btn | GPIO 17 | Internal pull-up

Stop button | GPIO 27 | Internal pull-up

Buzzer signal | GPIO 12 | PWM1

Buzzer GND | GND | Any GND pin

Pin Diagram (color-coded by function)

Pi Zero 2 W - 40-pin Header

# 3. 3D Printing

The BabyBox has three printed parts: the enclosure body, the lid, and figurine bases. All parts are designed in OpenSCAD and printed on a Bambu Lab P2S (or any FDM printer with a 256 x 256 mm bed).

## Recommended Print Settings

Parameter | Value
material | PETG
nozzle | 0.4 mm
layer_height | 0.2 mm
infill | 20 %
perimeters | 3
top_layers | 5
bottom_layers | 4
supports | None (designed support-free)

## Part A: Enclosure Body

Dimensions: 150 x 110 x 63 mm (body height without lid). Wall thickness: 3 mm. Corner radius: 5 mm.
Floor thickness: 3 mm.
- Print UPRIGHT (open top facing up). No supports needed.
- The breadboard bay is a recess in the floor -- prints as part of the body.
- Four M3 screw posts at the corners accept screws from the lid.
- Button holes (12 mm dia) and LED window (55 mm wide) are on the front wall.
- Port cutouts (mini-HDMI, 2x micro-USB, microSD) are on the back/side walls.

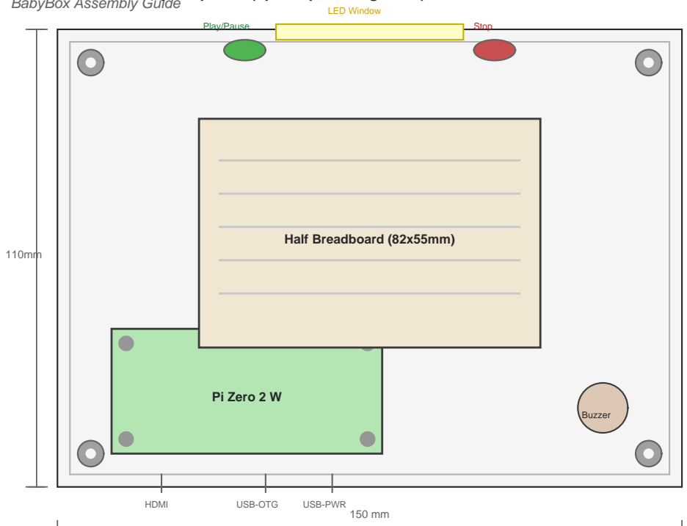
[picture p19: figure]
Pi Zero 2 W; HDMI; USB-OTG; USB-PWR; Half Breadboard (82x55mm); Buzzer; Play/Pause; Stop; LED Window

Enclosure Body - Top View (open top, looking down)

## Part B: Enclosure Lid

Dimensions: 150 x 110 x 12 mm.
The lid has a 3 mm nesting lip that fits inside the body opening.
- Print UPSIDE-DOWN (top surface on the build plate for a smooth finish).
- RFID module (MFRC522) mounts on standoffs hanging from the ceiling.
- Two magnet bosses enclose the neodymium magnets (see Section 4).
- A 36 mm engraved ring on the top surface marks the figurine placement zone.
- Four M3 clearance holes at the corners align with the body screw posts.
Lid - Bottom View (looking up into the lid)

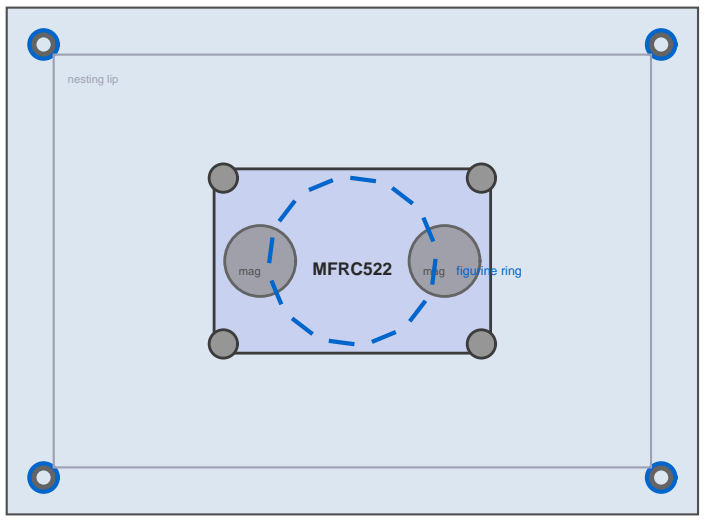
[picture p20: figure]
mag; MFRC522; mag figurine ring; nesting lip

## Part C: Figurine Base

Diameter: 35 mm. Height: 6 mm.
Chamfer: 0.8 mm on the bottom edge.
All figurines share the same base for consistent magnet alignment.
- Print RIGHT-SIDE UP (flat bottom on build plate).
- Two magnet pockets (6.3 mm dia, 3.2 mm deep) spaced 20 mm apart.
- Shallow RFID recess (25.5 mm dia, 0.5 mm deep) on the bottom face.
- Magnets inserted via pause-and-insert at Z = 4.2 mm (see Section 4).

# 4. Hidden Magnet Insertion

WARNING: Neodymium magnets are extremely dangerous if swallowed by a child. The pause-and-insert technique fully encloses each magnet inside solid plastic with no access points. NEVER leave magnets accessible. Always verify the seal layers printed correctly after resuming.

Both the lid and figurine bases use the same technique: the print is paused at a specific Z height, magnets are dropped into the open cavities, and printing resumes to seal them with solid layers above.

## Pause Heights

Part | Pause Z | Seal below | Cavity | Seal above
Figurine base (right-side up) | 4.2 mm | 1.0 mm | 3.2 mm | 1.7999999999999998 mm
Lid (upside-down) | 4.2 mm | 1.0 mm | 3.2 mm | ~2.0 mm (top wall)

## Step-by-Step Procedure

1. Slice the part in Bambu Studio and add a pause (M600) at the target Z height. For both figurine bases and the lid, pause at Z = 4.2 mm.
2. Start the print. When the printer pauses, the cavities will be open cylinders with a solid floor of 1.0 mm below.
3. Check magnet polarity BEFORE inserting! Use a reference magnet taped to the build plate with the correct pole facing up. Each new magnet must ATTRACT the reference (i.e., opposite poles face each other).
4. Drop one magnet into each cavity. It should sit flush or slightly below the rim. If it sticks up, the pocket depth is wrong -- do not continue.
5. Resume the print. The printer will lay solid layers over the magnets, permanently sealing them inside.
6. After the print completes, verify the top surface is smooth and fully sealed. Try to feel or pry out the magnets --you should not be able to.

## Figurine Base Cross-Section

Figurine Base Cross-Section

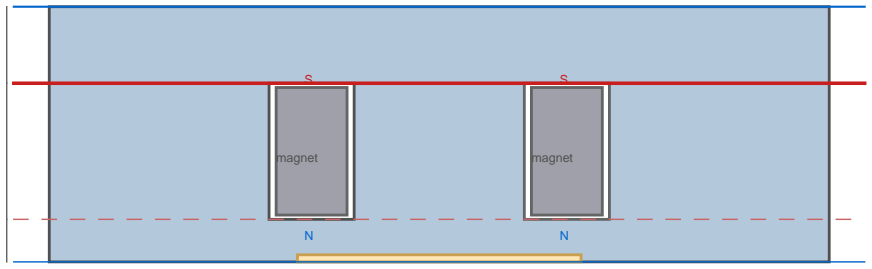
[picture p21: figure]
magnet

RFID sticker (bottom)

Z = 0 mm (build plate)

Z = 1.0 mm (seal floor)

Z = 4.2 mm PAUSE HERE

Z = 6 mm (top)

1.0mm

3.2mm

1.8mm

## Lid Cross-Section (printed upside-down)

Lid Cross-Section (printed upside-down)

magnet

N

S

magnet

N

S
Z = 0 mm (build plate)

Z = 1.0 mm (seal floor)

Z = 4.2 mm PAUSE HERE

Z = 12 mm (top)

1.0mm

3.2mm

7.8mm

## Polarity Reference

All magnets in the BabyBox must have matching polarity so figurine magnets ATTRACT the lid magnets. Use this system:
1. Mark one magnet with a dot of paint on its NORTH face. This is your reference.
2. When inserting magnets into the LID (printed upside-down), place them with the NORTH (dotted) face UP (toward you, away from the build plate).
3. When inserting magnets into FIGURINE BASES, place them with the SOUTH (un-dotted) face UP.
4. Test: after both parts are printed, place the figurine on the lid. The magnets should snap together firmly.

## Assembled View: Figurine on Lid

Figurine on Lid - Cross Section (assembled)

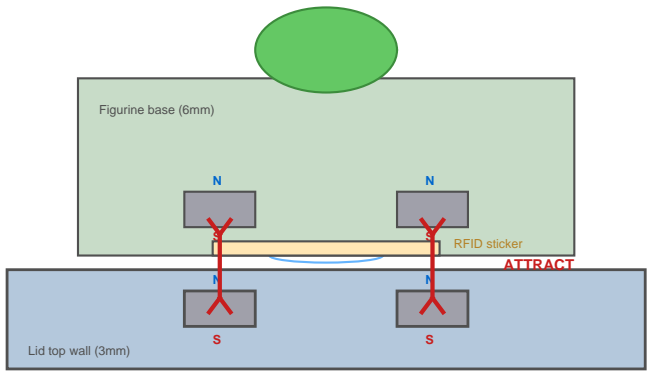
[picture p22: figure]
Lid top wall (3mm); Figurine base (6mm); RFID sticker ATTRACT

MFRC522 antenna

Figurine top (decorative)

~0mm gap

(magnets snap
together)

~8mm

# 5. Electronics Mounting

## Raspberry Pi Zero 2 W

The Pi mounts on four M2.5 standoffs (5 mm tall) near the back-left corner of the enclosure body. Use M2.5 x 6 mm screws from above.
- Ports face the back wall: mini-HDMI, 2x micro-USB (OTG + power).
- The microSD slot faces the left side wall.
- Ensure the Pi sits level and does not contact the floor (standoffs provide clearance).
- Flash Raspberry Pi OS Lite to the SD card before mounting.

## MFRC522 RFID Module

The MFRC522 mounts on four M2 standoffs hanging from the lid ceiling, centered on the lid. The antenna faces upward toward the figurine placement zone.
- Module dimensions: 60 x 40 x 4 mm (8 mm with header pins).
- Mounting holes: M2, spaced 56 x 36 mm.
- Use M2 x 8 mm screws from below (through the standoffs into the module).
- The module must sit as close to the lid's inner ceiling as possible for best read range.
- Total distance to figurine RFID tag: ~3 mm wall + ~5 mm figurine base = ~8 mm (well within the 30 mm read range).

## Half Breadboard

A half-size breadboard (82 x 55 mm) sits in a recessed bay in the enclosure floor. This provides a prototyping area for wiring the MFRC522, buttons, buzzer, and LED strip without soldering.
- The bay is 83 x 56 mm (with 0.5 mm tolerance per side).
- The breadboard sits flush with the floor surface.
- Peel off the adhesive backing and press into the bay, or leave it friction-fit.

## Buttons

Two 6x6 mm tactile buttons mount through 12 mm holes in the front wall. Use button caps (12 mm round) for a toddler-friendly surface.
- Left button (Play/Pause): GPIO 17, with internal pull-up.
- Right button (Stop): GPIO 27, with internal pull-up.
- Buttons are spaced 60 mm apart, centered on the front wall.
- Wire one leg to the GPIO pin and the opposite leg to GND.

## WS2812 LED Strip

An 8-LED WS2812 strip (51 x 10 mm) mounts behind the LED window on the front wall. The LEDs shine outward through the window slot.
- Window dimensions: 55 mm wide x 12 mm tall.
- A 5 mm deep channel behind the window holds the strip.

- Adhere the strip with its self-adhesive backing, LEDs facing outward.
- DIN connects to GPIO 18 (PWM0). 5V and GND to the Pi header.

## Passive Buzzer

A 12 mm passive buzzer sits in a ring cradle in the back-right corner of the floor.
- Cradle outer diameter: 15 mm, inner: 12.4 mm.
- Signal pin connects to GPIO 12 (PWM1). GND to any ground pin.
- Passive buzzers require a PWM signal to produce tones (unlike active buzzers).

# 6. Wiring Guide

All wiring goes through the half breadboard. Use jumper wires (male-to-female for the Pi header, male-to-male for the breadboard).
Wiring Overview

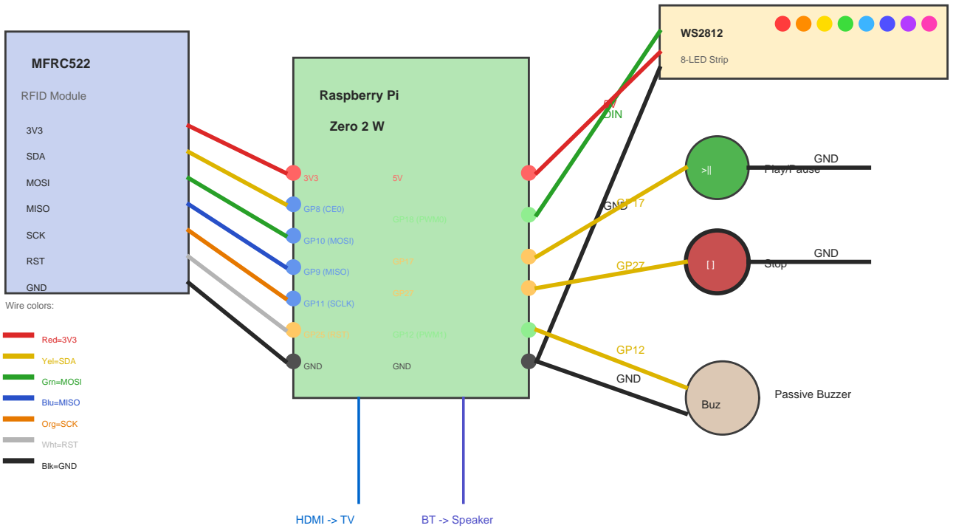
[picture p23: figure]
Raspberry Pi; Zero 2 W; GP10 (MOSI); GP9 (MISO); GP11 (SCLK); GP25 (RST); GND; GP18 (PWM0); GP12 (PWM1); MFRC522; RFID Module; SDA; MOSI; MISO; SCK; RST; Wire colors:; Red=3V3; Yel=SDA; Grn=MOSI; Blu=MISO; Org=SCK; Wht=RST; Blk=GND; 8-LED Strip; DIN; Play/Pause; Stop; Buz; Passive Buzzer; HDMI -> TV; BT -> Speaker

## MFRC522 RFID Module (7 wires)

MFRC522 Pin | Wire Color (suggested) | Pi Header Pin
SDA | Yellow | GPIO 8 (Pin 24, CE0)
SCK | Orange | GPIO 11 (Pin 23, SCLK)
MOSI | Green | GPIO 10 (Pin 19, MOSI)
MISO | Blue | GPIO 9 (Pin 21, MISO)
RST | White | GPIO 25 (Pin 22)
3.3V | Red | 3.3 V (Pin 1 or 17)
GND | Black | GND (Pin 6)

WARNING: The MFRC522 operates at 3.3 V. NEVER connect it to 5 V -- this will permanently damage the module.

## WS2812 LED Strip (3 wires)

LED Pin | Wire Color | Pi Header Pin
DIN | Green | GPIO 18 (Pin 12, PWM0)
5V | Red | 5 V (Pin 2 or 4)
GND | Black | GND (Pin 9)

## Buttons (4 wires total)

Button | Leg A | Leg B
Play/Pause | GPIO 17 (Pin 11) | GND (Pin 14)
Stop | GPIO 27 (Pin 13) | GND (Pin 14 or 20)

No external pull-up resistors needed -- the software enables internal pull-ups.

## Passive Buzzer (2 wires)

Buzzer Pin | Wire Color | Pi Header Pin
Signal (+) | Yellow | GPIO 12 (Pin 32, PWM1)
GND (-) | Black | GND (Pin 34)

NOTE: Route wires neatly and keep them away from the RFID antenna area in the lid. Loose wires near the MFRC522 can cause interference and reduce read range.

# 7. Figurine Construction

## Base Printing

All figurines share a standard base: 35 mm diameter, 6 mm tall. The base has two magnet pockets (6.3 mm dia, 3.2 mm deep) spaced 20 mm apart, and a shallow RFID recess (25.5 mm dia) on the bottom.
1. Open hardware/figurines/base-template.scad in OpenSCAD.
2. Set render_part = "base" and press F6 to render.
3. Export as STL. Import into Bambu Studio.
4. Use PETG, 0.2 mm layer height, 20% infill.
5. Add a pause at Z = 4.2 mm for magnet insertion.
6. Print right-side up (flat bottom on bed).

## Magnet Insertion

Follow the procedure in Section 4 (Hidden Magnet Insertion). Insert magnets at the pause, with the correct polarity (SOUTH face up for bases).

## RFID Sticker Application

1. Take a 25 mm MIFARE 13.56 MHz coin sticker.
2. Peel off the backing to expose the adhesive.
3. Center the sticker on the BOTTOM face of the figurine base, inside the shallow recess (25.5 mm dia).
4. Press firmly. The sticker should sit flush in the recess.
5. Test: hold the base near the MFRC522 module. The tag UID should be read successfully at up to ~25 mm distance.

## Figurine Top (Decorative Shell)

The top part of each figurine is the decorative character or object that the child interacts with. There are two approaches:
Option A: AI-Generated (Meshy AI + Blender)
1. Go to meshy.ai and generate a 3D model from a text prompt (e.g., "cute cartoon dinosaur, low poly, smooth").
2. Download the model as OBJ or GLB.
3. Open Blender. Import the Meshy model and the figurine base STL.
4. Position the decorative top on top of the base. Boolean-union them together.
5. Verify the magnet pockets and RFID recess are not obstructed.
6. Export as STL. Slice in Bambu Studio and print.
Option B: Simple Geometric Shape (OpenSCAD)
For simpler figurines, you can add a geometric top directly in OpenSCAD (cylinder, sphere, cone, etc.) on top of the base template.

## Figurine Design Guidelines

- Total height: 40-60 mm (base + top). Easy for toddler hands.
- Base diameter: 35 mm (standardized for magnet alignment).
- No small detachable parts. Everything is one solid piece after assembly.
- Bright colors. Multi-color prints possible with Bambu AMS.
- Minimal overhangs to avoid supports.
- Test each figurine on the box before giving to the child.

# 8. Final Assembly Sequence

Follow these steps in order to assemble a complete BabyBox from printed parts and electronics.
1. Print the enclosure BODY (Part A). Inspect for clean button holes, LED window, port cutouts, and screw posts.
2. Print the enclosure LID (Part B) upside-down. Pause at Z = 4.2 mm and insert 2x magnets (NORTH face up). Resume and let it complete.
3. Print at least 2 figurine BASES (Part C). Pause at Z = 4.2 mm and insert 2x magnets per base (SOUTH face up). Resume and complete.
4. Test magnet polarity: place a figurine base on the lid. The magnets should snap together firmly and align the base over the engraved ring.
5. Mount the Raspberry Pi Zero 2 W on its standoffs in the body using 4x M2.5 screws. Ports face the back wall.
6. Mount the MFRC522 RFID module on its standoffs under the lid ceiling using 4x M2 screws. Antenna faces upward.
7. Place the half breadboard in the floor recess. Press down to seat it.
8. Wire the MFRC522 to the Pi header (7 wires: SDA, SCK, MOSI, MISO, RST, 3.3V, GND). Route wires through the breadboard.
9. Wire the WS2812 LED strip (DIN to GPIO 18, 5V, GND). Adhere the strip behind the LED window with LEDs facing outward.
10. Wire the two buttons (Play/Pause to GPIO 17 + GND, Stop to GPIO 27 + GND). Mount buttons through the front wall holes with caps.
11. Wire the passive buzzer (signal to GPIO 12, GND). Seat it in the back-right cradle.
12. Flash Raspberry Pi OS Lite to the microSD card. Insert it into the Pi.
13. Connect a 5V 3A micro-USB power supply to the Pi's power port (the one further from the HDMI port). Verify the Pi boots.
14. Place the lid on the body. Align the nesting lip and screw posts. Secure with 4x M3 screws at the corners.
15. Attach RFID stickers to figurine bases (centered in the bottom recess). Glue or attach decorative tops to the bases.
16. Test: place a figurine on the lid. The RFID tag should be read, the LEDs should animate, and media should play. Connect a Bluetooth speaker and verify audio routing.

# 9. Safety Notes

WARNING: This device is intended for toddlers (ages 1-4). Safety is paramount. Review all points below before allowing a child to use the BabyBox.

## Magnet Safety

- ALL magnets MUST be fully enclosed inside 3D-printed plastic using the pause-and-insert technique. No magnets should be accessible.
- After printing, verify the seal: the top surface should be smooth and continuous with no visible cavities or holes.
- If a print fails mid-seal (power outage, filament runout), DISCARD the part. Do not use it with exposed magnets.
- Neodymium magnets are extremely dangerous if swallowed. Two magnets swallowed separately can attract through intestinal walls, causing perforation, obstruction, or death.
- Keep loose magnets locked away during assembly.

## Electrical Safety

- Use only a regulated 5V power supply. Never exceed 5V.
- The MFRC522 operates at 3.3V. Never connect it to 5V.
- Keep all wiring inside the enclosed box. No exposed connections.
- The enclosure should be fully closed (lid screwed on) during use.
- Do not use the device near water or liquids.
- Unplug the power supply when not in use or when opening the enclosure.

## Volume and Hearing

- All audio goes to an external Bluetooth speaker.
- Set the speaker volume to a safe level BEFORE giving it to the child.
- The American Academy of Pediatrics recommends keeping volume below 75 dB for extended listening.
- Place the speaker at least 1 meter from the child when possible.

## Screen Time

- The BabyBox has a built-in daily video limit system.
- Set appropriate limits in the web UI (Settings page).
- Audio content is unlimited; only video counts against the daily limit.
- The box provides LED + buzzer feedback when the video limit is reached.
- Supervise screen time for children under 2 (AAP recommendation).

## Physical Safety

- All enclosure corners are rounded (5 mm radius).
- Walls are 3 mm thick PETG -- sturdy enough for toddler handling.
- Figurines should be inspected regularly for cracks. If a crack exposes a magnet, remove the figurine immediately.

- The device is not a toy -- supervise initial use sessions.
- Keep small parts (screws, wire scraps) away from children during assembly.

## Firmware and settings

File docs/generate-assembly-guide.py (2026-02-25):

#!/usr/bin/env python3
"""
BabyBox Assembly Guide — PDF Generator
=======================================
Generates a comprehensive assembly guide covering 3D printing, magnet insertion,
electronics mounting, wiring, figurine construction, and final assembly.

Dependencies: fpdf2  (pip install fpdf2)
Output:       docs/BabyBox-Assembly-Guide.pdf

Usage:
    source docs/.venv/bin/activate
    python3 docs/generate-assembly-guide.py
"""

import textwrap
from datetime import date
from pathlib import Path

from fpdf import FPDF

# ─────────────────────────────────────────────────────────────
# Data Constants (from SPEC.md, common-params.scad, etc.)
# ─────────────────────────────────────────────────────────────

BOM = [
    ("Raspberry Pi Zero 2 W",           "1",  "Purchase",       "~$15"),
    ("MicroSD card (32 GB+)",            "1",  "Purchase",       "~$8"),
    ("MFRC522 RFID Module",              "1",  "Sensor kit",     "--"),
    ("RFID coin stickers (25mm, 13.56 MHz)", "10", "Purchase",   "~$5"),
    ("Neodymium magnets (6x3mm disc)",   "20+","Purchase",       "~$5"),
    ("Bluetooth speaker",                "1",  "Already owned",  "~$0-20"),
    ("WS2812 RGB 8-LED strip",           "1",  "Sensor kit",     "--"),
    ("Passive buzzer",                   "1",  "Sensor kit",     "--"),
    ("Tactile buttons (6x6mm)",          "2",  "Sensor kit",     "--"),
    ("Resistors / wires / breadboard",   "1",  "Sensor kit",     "--"),
    ("5 V 3 A micro-USB power supply",   "1",  "Purchase",       "~$8"),
    ("Mini-HDMI to HDMI cable",          "1",  "Purchase",       "~$5"),
    ("3D-printed enclosure + figurines", "1",  "Bambu Lab P2S",  "~$5 filament"),
]

GPIO_PINS = [
    ("MFRC522 SDA",  "GPIO 8",  "SPI0 CE0"),
    ("MFRC522 SCK",  "GPIO 11", "SPI0 SCLK"),
    ("MFRC522 MOSI", "GPIO 10", "SPI0 MOSI"),
    ("MFRC522 MISO", "GPIO 9",  "SPI0 MISO"),
    ("MFRC522 RST",  "GPIO 25", "General GPIO"),
    ("MFRC522 3.3 V","3.3 V",   "Pin 1 or 17"),
    ("MFRC522 GND",  "GND",     "Pin 6, 9, 14, 20, 25, 30, 34, 39"),
    ("WS2812 DIN",   "GPIO 18", "PWM0"),
    ("WS2812 5 V",   "5 V",     "Pin 2 or 4"),
    ("WS2812 GND",   "GND",     "Any GND pin"),
    ("Play/Pause btn","GPIO 17", "Internal pull-up"),
    ("Stop button",  "GPIO 27", "Internal pull-up"),
    ("Buzzer signal", "GPIO 12", "PWM1"),
    ("Buzzer GND",   "GND",     "Any GND pin"),
]

ENCLOSURE = {
    "outer_l": 150, "outer_w": 110, "outer_h": 75,
    "wall": 3, "corner_r": 5, "lid_h": 12, "body_h": 63,
    "floor_h": 3,
}
FIGURINE_BASE = {
    "dia": 35, "height": 6,
    "magnet_pocket_dia": 6.3, "magnet_pocket_h": 3.2,
    "magnet_seal_h": 1.0, "magnet_spacing": 20,
    "rfid_recess_dia": 25.5, "rfid_recess_h": 0.5,
    "chamfer": 0.8,
}
MAGNETS = {"dia": 6, "h": 3, "pocket_dia": 6.3, "pocket_h": 3.2, "spacing": 20, "seal_h": 1.0}

PRINT_SETTINGS = {
    "material": "PETG",
    "nozzle": "0.4 mm",
    "layer_height": "0.2 mm",
    "infill": "20 %",
    "perimeters": "3",
    "top_layers": "5",
    "bottom_layers": "4",
    "supports": "None (designed support-free)",
}

# Colors
COLOR_DARK   = (40, 40, 40)
COLOR_ACCENT = (0, 102, 204)
COLOR_RED    = (200, 30, 30)
COLOR_GREEN  = (30, 130, 60)
COLOR_WARN   = (220, 160, 0)
COLOR_GRAY   = (100, 100, 100)
COLOR_LIGHT  = (240, 240, 240)

# Wire colors for diagrams
WIRE_YELLOW = (220, 180, 0)
WIRE_ORANGE = (230, 120, 0)
WIRE_GREEN  = (40, 160, 40)
WIRE_BLUE   = (40, 80, 200)
WIRE_WHITE  = (180, 180, 180)
WIRE_RED    = (220, 40, 40)
WIRE_BLACK  = (40, 40, 40)

# Pin highlight colors
PIN_SPI   = (100, 149, 237)   # cornflower blue
PIN_PWM   = (144, 238, 144)   # light green
PIN_GPIO  = (255, 200, 100)   # gold
PIN_POWER = (255, 100, 100)   # red
PIN_GND   = (80, 80, 80)      # dark gray
PIN_UNUSED = (200, 200, 200)  # light gray


# ─────────────────────────────────────────────────────────────
# AssemblyGuide class
# ─────────────────────────────────────────────────────────────

class AssemblyGuide(FPDF):
    """Custom FPDF subclass with helpers for a technical assembly guide."""

    MARGIN = 15
    section_num = 0

    def __init__(self):
        super().__init__(orientation="P", unit="mm", format="A4")
        self.set_auto_page_break(auto=True, margin=20)
        self.set_margins(self.MARGIN, self.MARGIN, self.MARGIN)

    # --- Page chrome ---
    def header(self):
        if self.page_no() <= 2:
            return
        self.set_font("Helvetica", "I", 8)
        self.set_text_color(*COLOR_GRAY)
        self.cell(0, 6, "BabyBox Assembly Guide", align="L")
        self.ln(8)

    def footer(self):
        if self.page_no() <= 1:
            return
        self.set_y(-15)
        self.set_font("Helvetica", "I", 8)
        self.set_text_color(*COLOR_GRAY)
        self.cell(0, 10, f"Page {self.page_no()}", align="C")

    # --- Content helpers ---

    def section_title(self, title):
        self.section_num += 1
        label = f"{self.section_num}.  {title}"
        self.add_page()
        self.start_section(label)
        self.set_font("Helvetica", "B", 18)
        self.set_text_color(*COLOR_DARK)
        self.cell(0, 12, label, new_x="LMARGIN", new_y="NEXT")
        y = self.get_y()
        self.set_draw_color(*COLOR_ACCENT)
        self.set_line_width(0.8)
        self.line(self.MARGIN, y, self.w - self.MARGIN, y)
        self.ln(6)

    def subsection(self, title):
        self._ensure_space(14)
        self.set_font("Helvetica", "B", 13)
        self.set_text_color(*COLOR_ACCENT)
        self.cell(0, 9, title, new_x="LMARGIN", new_y="NEXT")
        self.set_text_color(*COLOR_DARK)
        self.ln(2)

    def body_text(self, text):
        self.set_font("Helvetica", "", 10)
        self.set_text_color(*COLOR_DARK)
        self.multi_cell(0, 5, text)
        self.ln(2)

    def bold_text(self, text):
        self.set_font("Helvetica", "B", 10)
        self.set_text_color(*COLOR_DARK)
        self.multi_cell(0, 5, text)
        self.ln(2)

    def note_box(self, text, kind="NOTE"):
        color = COLOR_RED if kind == "WARNING" else COLOR_ACCENT
        prefix = f"{kind}: "
        full_text = prefix + text

        self.set_font("Helvetica", "", 10)
        page_w = self.w - 2 * self.MARGIN
        inner_w = page_w - 10

        char_w = self.get_string_width("x")
        chars_per_line = max(1, int(inner_w / char_w))
        wrapped = textwrap.fill(full_text, width=chars_per_line)
        n_lines = wrapped.count("\n") + 1
        block_h = n_lines * 5 + 8

        self._ensure_space(block_h + 4)
        y0 = self.get_y()
        x0 = self.MARGIN

        self.set_fill_color(*color)
        self.rect(x0, y0, 3, block_h, "F")

        bg = (255, 235, 235) if kind == "WARNING" else (230, 240, 255)
        self.set_fill_color(*bg)
        self.rect(x0 + 3, y0, page_w - 3, block_h, "F")

        self.set_xy(x0 + 7, y0 + 3)
        self.set_font("Helvetica", "B", 10)
        self.set_text_color(*color)
        self.write(5, prefix)
        self.set_font("Helvetica", "", 10)
        self.set_text_color(*COLOR_DARK)
        self.multi_cell(inner_w - 4, 5, text)

        actual_y = self.get_y()
        self.set_y(max(y0 + block_h, actual_y) + 4)

    def numbered_steps(self, steps):
        for i, step in enumerate(steps, 1):
            self._ensure_space(12)
            self.set_font("Helvetica", "B", 10)
            self.set_text_color(*COLOR_ACCENT)
            self.cell(8, 5, f"{i}.", new_x="END")
            self.set_font("Helvetica", "", 10)
            self.set_text_color(*COLOR_DARK)
            x = self.get_x()
            self.multi_cell(self.w - self.MARGIN - x, 5, step)
            self.ln(1.5)

    def bullet_list(self, items):
        for item in items:
            self._ensure_space(10)
            self.set_font("Helvetica", "", 10)
            self.set_text_color(*COLOR_DARK)
            self.cell(6, 5, "-", new_x="END")
            x = self.get_x()
            self.multi_cell(self.w - self.MARGIN - x, 5, item)
            self.ln(1)

    def make_table(self, headers, rows, col_widths=None):
        page_w = self.w - 2 * self.MARGIN
        if col_widths is None:
            col_widths = [page_w / len(headers)] * len(headers)

        self._ensure_space(20)

        with self.table(
            col_widths=col_widths,
            text_align="LEFT",
            line_height=self.font_size * 2.2,
            first_row_as_headings=True,
            cell_fill_color=COLOR_LIGHT,
            cell_fill_mode="ROWS",
        ) as table:
            hrow = table.row()
            self.set_font("Helvetica", "B", 9)
            for h in headers:
                hrow.cell(h)
            self.set_font("Helvetica", "", 9)
            for row_data in rows:
                r = table.row()
                for cell_text in row_data:
                    r.cell(cell_text)
        self.ln(3)

    def _ensure_space(self, needed_mm):
        remaining = self.h - self.get_y() - 20
        if remaining < needed_mm:
            self.add_page()

    # --- Drawing helpers ---

    def _label(self, x, y, text, size=7, color=COLOR_DARK, align="L", bold=False):
        """Place a label at absolute position without moving cursor."""
        old_x, old_y = self.get_x(), self.get_y()
        style = "B" if bold else ""
        self.set_font("Helvetica", style, size)
        self.set_text_color(*color)
        self.text(x, y, text)
        self.set_xy(old_x, old_y)

    def _pin_circle(self, cx, cy, r, color, label="", label_side="L", label_size=5.5):
        """Draw a filled pin circle with an optional label."""
        self.set_fill_color(*color)
        self.set_draw_color(60, 60, 60)
        self.set_line_width(0.2)
        self.ellipse(cx - r, cy - r, 2 * r, 2 * r, "DF")
        if label:
            self.set_font("Helvetica", "", label_size)
            self.set_text_color(*COLOR_DARK)
            lw = self.get_string_width(label)
            if label_side == "L":
                self.text(cx - r - lw - 1.5, cy + 1.5, label)
            else:
                self.text(cx + r + 1.5, cy + 1.5, label)

    def _wire(self, x1, y1, x2, y2, color, label="", label_pos="mid"):
        """Draw a colored wire between two points with an optional label."""
        self.set_draw_color(*color)
        self.set_line_width(0.8)
        self.line(x1, y1, x2, y2)
        if label:
            self.set_font("Helvetica", "", 6)
            self.set_text_color(*color)
            if label_pos == "mid":
                mx = (x1 + x2) / 2
                my = (y1 + y2) / 2
                self.text(mx + 1, my - 1, label)

    def _rounded_rect(self, x, y, w, h, r, style="D"):
        """Draw a rectangle (rounded corners approximated with regular rect)."""
        self.set_line_width(0.3)
        self.rect(x, y, w, h, style)

    def _component_box(self, x, y, w, h, label, color=(180, 210, 240)):
        """Draw a labeled component rectangle."""
        self.set_fill_color(*color)
        self.set_draw_color(60, 60, 60)
        self.set_line_width(0.4)
        self.rect(x, y, w, h, "DF")
        self.set_font("Helvetica", "B", 7)
        self.set_text_color(*COLOR_DARK)
        lw = self.get_string_width(label)
        self.text(x + (w - lw) / 2, y + h / 2 + 2, label)

    def _dimension_line(self, x1, y, x2, label):
        """Draw a dimensioning line with arrowheads and label."""
        self.set_draw_color(*COLOR_GRAY)
        self.set_line_width(0.25)
        # line
        self.line(x1, y, x2, y)
        # arrowheads (small ticks)
        self.line(x1, y - 1.5, x1, y + 1.5)
        self.line(x2, y - 1.5, x2, y + 1.5)
        # label
        self.set_font("Helvetica", "", 6)
        self.set_text_color(*COLOR_GRAY)
        lw = self.get_string_width(label)
        mx = (x1 + x2) / 2 - lw / 2
        self.text(mx, y - 2, label)


# ─────────────────────────────────────────────────────────────
# Diagram Drawing Functions
# ─────────────────────────────────────────────────────────────

def draw_cover_enclosure(pdf: AssemblyGuide, cx, y_top):
    """Draw a 3D-ish enclosure sketch on the cover page."""
    # Front face
    w, h = 100, 48
    x = cx - w / 2
    y = y_top
    d = 15  # 3D depth offset

    pdf.set_draw_color(*COLOR_DARK)
    pdf.set_line_width(0.6)

    # Top face (parallelogram) — draw first so front face overlaps
    pdf.set_fill_color(200, 220, 245)
    top_pts = [(x, y), (x + d, y - d), (x + w + d, y - d), (x + w, y)]
    pdf.polygon(top_pts, style="DF")

    # Right face (parallelogram)
    pdf.set_fill_color(180, 200, 230)
    right_pts = [(x + w, y), (x + w + d, y - d), (x + w + d, y + h - d), (x + w, y + h)]
    pdf.polygon(right_pts, style="DF")

    # Front face (on top)
    pdf.set_fill_color(230, 240, 250)
    pdf.rect(x, y, w, h, "DF")

    # Figurine placement circle on top
    top_cx = cx + d / 2
    top_cy = y - d / 2
    pdf.set_draw_color(*COLOR_ACCENT)
    pdf.set_line_width(0.8)
    pdf.ellipse(top_cx - 12, top_cy - 5, 24, 10, "D")

    # Two magnets on top (small dots)
    pdf.set_fill_color(*COLOR_GRAY)
    pdf.ellipse(top_cx - 7, top_cy - 1.5, 3, 3, "F")
    pdf.ellipse(top_cx + 4, top_cy - 1.5, 3, 3, "F")

    # Buttons on front
    btn_y = y + h * 0.35
    pdf.set_fill_color(80, 180, 80)
    pdf.set_draw_color(60, 60, 60)
    pdf.set_line_width(0.3)
    pdf.ellipse(x + 25, btn_y, 10, 10, "DF")  # play/pause
    pdf.set_fill_color(200, 80, 80)
    pdf.ellipse(x + 65, btn_y, 10, 10, "DF")  # stop

    # Button labels
    pdf._label(x + 27.5, btn_y + 6, ">||", size=5, color=(255, 255, 255))
    pdf._label(x + 69, btn_y + 6, "[ ]", size=5, color=(255, 255, 255))

    # LED strip on front
    led_y = y + h * 0.7
    for i in range(8):
        lx = x + 20 + i * 8
        colors = [(255, 60, 60), (255, 140, 0), (255, 220, 0), (60, 220, 60),
                  (60, 180, 255), (80, 80, 255), (180, 60, 255), (255, 60, 180)]
        pdf.set_fill_color(*colors[i])
        pdf.ellipse(lx, led_y, 5, 5, "F")

    # Top label
    pdf._label(top_cx - 14, top_cy + 1, "place figurine", size=6, color=COLOR_ACCENT)

    # Dimensions
    dim_y = y + h + 6
    pdf._dimension_line(x, dim_y, x + w, "150 mm")
    pdf._dimension_line(x + w + 4, y, x + w + 4, "75 mm")
    pdf.set_draw_color(*COLOR_GRAY)
    pdf.line(x + w + 2, y, x + w + 6, y)
    pdf.line(x + w + 2, y + h, x + w + 6, y + h)
    pdf.set_font("Helvetica", "", 6)
    pdf.set_text_color(*COLOR_GRAY)


def draw_gpio_header(pdf: AssemblyGuide, x0, y0):
    """Draw the 40-pin GPIO header with color-coded pins."""
    # Pin definitions: (pin#, label, color, is_used)
    # Odd = left column, Even = right column
    pin_data = {
        1:  ("3V3",  PIN_POWER, True),   2:  ("5V",   PIN_POWER, True),
        3:  ("SDA",  PIN_UNUSED, False),  4:  ("5V",   PIN_POWER, True),
        5:  ("SCL",  PIN_UNUSED, False),  6:  ("GND",  PIN_GND, True),
        7:  ("GP4",  PIN_UNUSED, False),  8:  ("TXD",  PIN_UNUSED, False),
        9:  ("GND",  PIN_GND, True),     10:  ("RXD",  PIN_UNUSED, False),
        11: ("GP17", PIN_GPIO, True),    12:  ("GP18", PIN_PWM, True),
        13: ("GP27", PIN_GPIO, True),    14:  ("GND",  PIN_GND, True),
        15: ("GP22", PIN_UNUSED, False), 16:  ("GP23", PIN_UNUSED, False),
        17: ("3V3",  PIN_POWER, True),   18:  ("GP24", PIN_UNUSED, False),
        19: ("MOSI", PIN_SPI, True),     20:  ("GND",  PIN_GND, True),
        21: ("MISO", PIN_SPI, True),     22:  ("GP25", PIN_GPIO, True),
        23: ("SCLK", PIN_SPI, True),     24:  ("CE0",  PIN_SPI, True),
        25: ("GND",  PIN_GND, True),     26:  ("CE1",  PIN_UNUSED, False),
        27: ("ID",   PIN_UNUSED, False), 28:  ("ID",   PIN_UNUSED, False),
        29: ("GP5",  PIN_UNUSED, False), 30:  ("GND",  PIN_GND, True),
        31: ("GP6",  PIN_UNUSED, False), 32:  ("GP12", PIN_PWM, True),
        33: ("GP13", PIN_UNUSED, False), 34:  ("GND",  PIN_GND, True),
        35: ("GP19", PIN_UNUSED, False), 36:  ("GP16", PIN_UNUSED, False),
        37: ("GP26", PIN_UNUSED, False), 38:  ("GP20", PIN_UNUSED, False),
        39: ("GND",  PIN_GND, True),     40:  ("GP21", PIN_UNUSED, False),
    }

    pin_r = 2.2
    row_h = 5.5
    col_gap = 10
    total_h = 20 * row_h + 4  # 20 rows

    # Board background
    pdf.set_fill_color(60, 120, 60)
    pdf.set_draw_color(40, 80, 40)
    pdf.set_line_width(0.5)
    pdf.rect(x0, y0, 60, total_h, "DF")

    # Title
    pdf._label(x0 + 8, y0 + 5, "Pi Zero 2 W  -  40-pin Header", size=7,
               color=(220, 255, 220), bold=True)

    pin_start_y = y0 + 9

    # Usage annotations (right side)
    annotations = {
        11: "Play/Pause",
        12: "WS2812 DIN",
        13: "Stop btn",
        19: "RFID MOSI",
        21: "RFID MISO",
        22: "RFID RST",
        23: "RFID SCLK",
        24: "RFID SDA",
        32: "Buzzer",
    }

    for pin_num in range(1, 41):
        label, color, used = pin_data[pin_num]
        row = (pin_num - 1) // 2
        is_left = (pin_num % 2 == 1)

        if is_left:
            cx = x0 + 18
        else:
            cx = x0 + 18 + col_gap
        cy = pin_start_y + row * row_h

        # Draw pin
        pdf._pin_circle(cx, cy, pin_r, color,
                        label=f"{label}" if used else "",
                        label_side="L" if is_left else "R",
                        label_size=5)

        # Pin number
        pdf.set_font("Helvetica", "", 4)
        pdf.set_text_color(200, 200, 200)
        pdf.text(cx - 1.2, cy + 1, str(pin_num))

        # Annotation arrow for key pins
        if pin_num in annotations:
            ax = x0 + 60 + 3
            pdf.set_draw_color(*color)
            pdf.set_line_width(0.4)
            pdf.line(cx + pin_r, cy, ax, cy)
            pdf._label(ax + 1, cy + 1.5, annotations[pin_num], size=6, color=color)

    # Legend
    ly = y0 + total_h + 5
    legend_items = [
        ("SPI (RFID)", PIN_SPI),
        ("PWM (LED/Buzzer)", PIN_PWM),
        ("GPIO (Buttons/RST)", PIN_GPIO),
        ("Power (3V3/5V)", PIN_POWER),
        ("GND", PIN_GND),
        ("Unused", PIN_UNUSED),
    ]
    lx = x0
    for lbl, col in legend_items:
        pdf.set_fill_color(*col)
        pdf.set_draw_color(60, 60, 60)
        pdf.set_line_width(0.2)
        pdf.ellipse(lx, ly, 3, 3, "DF")
        pdf._label(lx + 4, ly + 2.5, lbl, size=6)
        lx += pdf.get_string_width(lbl) + 8

    return total_h + 14
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

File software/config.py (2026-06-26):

import os
from pathlib import Path

# Environment: "dev" for mock hardware, "pi" for real Pi hardware
ENV = os.getenv("BABYBOX_ENV", "pi")
IS_PI = ENV != "dev"

# Base paths
BASE_DIR = Path(os.getenv("BABYBOX_DATA_DIR", "/home/pi/babybox"))
MEDIA_DIR = BASE_DIR / "media"
AUDIO_DIR = MEDIA_DIR / "audio"
VIDEO_DIR = MEDIA_DIR / "video"
THUMBNAIL_DIR = MEDIA_DIR / "thumbnails"
DB_PATH = BASE_DIR / "babybox.db"

# GPIO pins
GPIO_RFID_RST = 25
GPIO_RFID_SDA = 8  # CE0
GPIO_LED_DIN = 18  # PWM0
GPIO_BUZZER = 12  # PWM1
GPIO_BTN_PLAY_PAUSE = 17
GPIO_BTN_STOP = 27

# LED strip
LED_COUNT = 8
LED_BRIGHTNESS = 128  # 0-255

# RFID
RFID_POLL_INTERVAL = 0.2  # seconds
RFID_DEDUP_WINDOW = 2.0  # ignore same UID within this window

# Button debounce
BUTTON_POLL_INTERVAL = 0.05  # seconds
BUTTON_DEBOUNCE_MS = 200

# Defaults for settings
DEFAULT_SETTINGS = {
    "daily_video_limit_count": "5",
    "daily_video_limit_minutes": "60",
    "limit_reset_hour": "6",
    "bt_speaker_mac": "",
    "volume": "80",
}

# Web server
WEB_HOST = "0.0.0.0"
WEB_PORT = 5000

# mpv config
MPV_AUDIO_DEVICE = "pulse"


def ensure_dirs():
    """Create media directories if they don't exist."""
    for d in (AUDIO_DIR, VIDEO_DIR, THUMBNAIL_DIR):
        d.mkdir(parents=True, exist_ok=True)

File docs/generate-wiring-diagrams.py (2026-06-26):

#!/usr/bin/env python3
"""Generate realistic Fritzing-style wiring diagrams for the BabyBox website.

Outputs SVG files into website/images/diagrams/:
  - wiring-stock.svg          : full stock-build wiring overview (Bluetooth audio)
  - wiring-wired-speaker.svg  : wired-speaker variant (KALLSUP driver + MAX98357A)
  - audio-bluetooth.svg       : stock Bluetooth audio option graphic

Run from anywhere:  python3 docs/generate-wiring-diagrams.py
"""

import os

OUT_DIR = os.path.join(os.path.dirname(os.path.abspath(__file__)), "..", "website", "images", "diagrams")

FONT = "Inter, -apple-system, 'Segoe UI', sans-serif"
MONO = "'SF Mono', 'Fira Code', monospace"

# Wire colors (match the website legend)
C = {
    "red":    "#D32F2F",   # power (3.3V / 5V)
    "black":  "#37352F",   # GND
    "yellow": "#E0A800",   # SDA / signal
    "orange": "#E07800",   # SCK / BCLK
    "green":  "#2E9E44",   # MOSI / DIN (data)
    "blue":   "#2F5FD0",   # MISO
    "white":  "#E8E8E8",   # RST / LRC
    "teal":   "#26A69A",   # moved-pin highlight
}


def darker(hex_color, f=0.62):
    h = hex_color.lstrip("#")
    r, g, b = (int(h[i:i + 2], 16) for i in (0, 2, 4))
    return f"#{int(r * f):02X}{int(g * f):02X}{int(b * f):02X}"


# ---------------------------------------------------------------- Pi Zero 2 W

PI_W, PI_H = 420, 190
HDR_INSET_X, HDR_Y, HDR_H = 24, 10, 40
HDR_W = PI_W - 2 * HDR_INSET_X
PITCH = HDR_W / 20.0


def pin_local(phys):
    """Local (x, y) of a physical header pin (1..40). Header along top edge.
    Even pins = outer/top row, odd pins = inner/bottom row (SD slot on left)."""
    col = (phys + 1) // 2
    x = HDR_INSET_X + PITCH * (col - 0.5)
    y = HDR_Y + (11 if phys % 2 == 0 else 29)
    return x, y


def pi_zero(ox, oy, used_pins, title="Raspberry Pi Zero 2 W"):
    """Render the Pi at (ox, oy). used_pins: {phys: (color, label)} highlights."""
    s = [f'<g transform="translate({ox},{oy})">']
    # drop shadow + board
    s.append(f'<rect x="3" y="5" width="{PI_W}" height="{PI_H}" rx="14" fill="#000" opacity="0.10"/>')
    s.append(f'<rect width="{PI_W}" height="{PI_H}" rx="14" fill="url(#pcbGreen)" stroke="#1B4D2A" stroke-width="2"/>')
    # mounting holes
    for hx, hy in ((16, 16), (PI_W - 16, 16), (16, PI_H - 16), (PI_W - 16, PI_H - 16)):
        s.append(f'<circle cx="{hx}" cy="{hy}" r="7" fill="#C9A227" stroke="#8C6E14" stroke-width="1.5"/>')
        s.append(f'<circle cx="{hx}" cy="{hy}" r="3.5" fill="#FAF6EC"/>')
    # header block
    s.append(f'<rect x="{HDR_INSET_X - 8}" y="{HDR_Y}" width="{HDR_W + 16}" height="{HDR_H}" rx="4" fill="#1A1A1A"/>')
    for p in range(1, 41):
        x, y = pin_local(p)
        s.append(f'<rect x="{x - 3.2:.1f}" y="{y - 3.2:.1f}" width="6.4" height="6.4" fill="#E6C35C" stroke="#9C7E20" stroke-width="0.8"/>')
    # pin 1 marker (square outline)
    x1, y1 = pin_local(1)
    s.append(f'<rect x="{x1 - 5.6:.1f}" y="{y1 - 5.6:.1f}" width="11.2" height="11.2" fill="none" stroke="#FFF" stroke-width="1.2"/>')
    s.append(f'<text x="{x1 - 12}" y="{y1 + 16}" font-family="{MONO}" font-size="9" fill="#CFE8D5">1</text>')
    x40, y40 = pin_local(40)
    s.append(f'<text x="{x40 + 6}" y="{y40 - 24}" font-family="{MONO}" font-size="9" fill="#CFE8D5">40</text>')
    # SoC + RAM
    s.append(f'<rect x="{PI_W / 2 - 32}" y="92" width="64" height="64" rx="4" fill="#2B2B2B" stroke="#111" stroke-width="1"/>')
    s.append(f'<text x="{PI_W / 2}" y="121" text-anchor="middle" font-family="{MONO}" font-size="8" fill="#888">BCM2710A1</text>')
    s.append(f'<text x="{PI_W / 2}" y="133" text-anchor="middle" font-family="{MONO}" font-size="7" fill="#666">+ 512MB RAM</text>')
    # SD slot (left edge)
    s.append(f'<rect x="-6" y="76" width="46" height="40" rx="3" fill="#9DA5AB" stroke="#6B7176" stroke-width="1.5"/>')
    s.append(f'<text x="18" y="100" text-anchor="middle" font-family="{FONT}" font-size="7.5" fill="#3A3F44" font-weight="600">microSD</text>')
    # camera connector (right edge)
    s.append(f'<rect x="{PI_W - 14}" y="72" width="14" height="48" rx="2" fill="#D8D2C4" stroke="#A89F8C" stroke-width="1"/>')
    # bottom edge ports: mini-HDMI, USB OTG, USB PWR
    for px, pw, lbl in ((96, 64, "mini-HDMI"), (218, 44, "USB (OTG)"), (286, 44, "USB (PWR)")):
        s.append(f'<rect x="{px}" y="{PI_H - 16}" width="{pw}" height="22" rx="3" fill="#AEB6BC" stroke="#787F85" stroke-width="1.5"/>')
        s.append(f'<rect x="{px + 6}" y="{PI_H - 10}" width="{pw - 12}" height="10" rx="2" fill="#42484D"/>')
        s.append(f'<text x="{px + pw / 2}" y="{PI_H + 22}" text-anchor="middle" font-family="{FONT}" font-size="9" fill="#636E72">{lbl}</text>')
    # silk title
    s.append(f'<text x="{PI_W / 2}" y="78" text-anchor="middle" font-family="{FONT}" font-size="12" font-weight="700" fill="#E8F5EC">{title}</text>')
    # used-pin highlights + tiny pin-number flags
    for p, (color, lbl) in used_pins.items():
        x, y = pin_local(p)
        s.append(f'<circle cx="{x}" cy="{y}" r="6.5" fill="none" stroke="{color}" stroke-width="2.5"/>')
        if lbl:
            ly = y - 14 if p % 2 == 0 else y + 18
            anchor_y = ly - 8 if p % 2 == 0 else ly - 8
            s.append(f'<g font-family="{MONO}" font-size="8.5" font-weight="700">'
                     f'<text x="{x}" y="{ly}" text-anchor="middle" fill="#FFF" stroke="#FFF" stroke-width="2.5" paint-order="stroke">{lbl}</text>'
                     f'<text x="{x}" y="{ly}" text-anchor="middle" fill="{darker(color, 0.8)}">{lbl}</text></g>')
    s.append("</g>")
    return "\n".join(s)


def pi_pin(ox, oy, phys):
    x, y = pin_local(phys)
    return ox + x, oy + y


# ------------------------------------------------------------------ Wires
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

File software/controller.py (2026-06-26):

import logging
import threading
from pathlib import Path
from typing import Optional

from software.config import AUDIO_DIR, VIDEO_DIR
from software.db import Database
from software.hardware.base import Buzzer, LEDStrip
from software.limits import check_video_limit
from software.models import MediaType, PlaybackState
from software.player import Player

logger = logging.getLogger(__name__)


class Controller:
    def __init__(self, db: Database, player: Player, leds: LEDStrip, buzzer: Buzzer):
        self._db = db
        self._player = player
        self._leds = leds
        self._buzzer = buzzer
        self._lock = threading.Lock()
        self._state = PlaybackState.IDLE
        self._current_log_id: Optional[int] = None
        self._current_media_id: Optional[int] = None
        self._current_tag_uid: Optional[str] = None
        self._was_last_video = False
        self._register_mode = False
        self._last_scanned_uid: Optional[str] = None

        # Wire up player end callback
        self._player._on_playback_end = self._on_playback_end

        # Start in idle
        self._leds.idle()

    @property
    def state(self) -> PlaybackState:
        return self._state

    @property
    def register_mode(self) -> bool:
        return self._register_mode

    @register_mode.setter
    def register_mode(self, value: bool):
        self._register_mode = value
        if value:
            logger.info("Register mode enabled")
        else:
            logger.info("Register mode disabled")

    @property
    def last_scanned_uid(self) -> Optional[str]:
        return self._last_scanned_uid

    @property
    def current_media_id(self) -> Optional[int]:
        return self._current_media_id

    @property
    def volume(self) -> int:
        return self._player.volume

    def set_volume(self, level: int):
        self._player.set_volume(level)

    def on_tag_scanned(self, uid: str):
        """Called by RFID thread when a tag is detected."""
        self._last_scanned_uid = uid

        if self._register_mode:
            logger.info("Register mode: captured UID %s", uid)
            self._buzzer.scan_confirm()
            self._leds.scan_feedback()
            return

        with self._lock:
            if self._state != PlaybackState.IDLE:
                logger.debug("Ignoring tag %s — state is %s", uid, self._state.value)
                return
            self._process_tag(uid)

    def _process_tag(self, uid: str):
        """Process a scanned tag. Must be called with _lock held."""
        # Look up tag → media mapping
        tag = self._db.get_tag(uid)
        if not tag:
            logger.warning("Unknown tag: %s", uid)
            self._buzzer.error()
            return

        media = self._db.get_media(tag.media_id)
        if not media:
            logger.error("Tag %s points to missing media %d", uid, tag.media_id)
            self._buzzer.error()
            return

        # Check limits for video
        self._state = PlaybackState.CHECK_LIMITS
        self._was_last_video = False

        if media.media_type == MediaType.VIDEO:
            stats = self._db.get_today_video_stats()
            settings = self._db.get_all_settings()
            max_count = int(settings.get("daily_video_limit_count", "5"))
            max_minutes = int(settings.get("daily_video_limit_minutes", "60"))

            result = check_video_limit(
                stats, max_count, max_minutes, media.duration_s or 0
            )

            if not result.allowed:
                logger.info("Video limit reached: %s", result.reason)
                self._buzzer.all_done()
                self._leds.all_done_feedback()
                self._state = PlaybackState.IDLE
                return

            if result.is_last:
                logger.info("This is the last allowed video")
                self._was_last_video = True
                self._buzzer.last_video_warning()
                self._leds.last_video_warning()

        # Load and play
        self._state = PlaybackState.LOADING
        self._buzzer.scan_confirm()
        self._leds.scan_feedback()

        # Determine file path
        if media.media_type == MediaType.VIDEO:
            filepath = VIDEO_DIR / media.filename
        else:
            filepath = AUDIO_DIR / media.filename

        if not filepath.exists():
            logger.error("Media file not found: %s", filepath)
            self._buzzer.error()
            self._state = PlaybackState.IDLE
            self._leds.idle()
            return

        # Log playback start
        self._current_media_id = media.id
        self._current_tag_uid = uid
        self._current_log_id = self._db.log_playback_start(media.id, uid)

        # Start playing
        self._state = PlaybackState.PLAYING
        self._leds.playing_animation()
        self._player.play(str(filepath), media.media_type)

    def _on_playback_end(self):
        """Called by player when playback ends naturally."""
        with self._lock:
            if self._state != PlaybackState.PLAYING:
                return

            self._state = PlaybackState.FINISHED
            logger.info("Playback finished")

            # Log completion
            if self._current_log_id:
                self._db.log_playback_end(self._current_log_id, completed=True)

            # Check if this was the last video
            if self._was_last_video:
                self._buzzer.all_done()
                self._leds.all_done_feedback()
            else:
                self._leds.off()

            self._cleanup_state()

    def on_play_pause(self):
        """Called by button thread on play/pause press."""
        with self._lock:
            if self._state == PlaybackState.PLAYING:
                self._player.pause_toggle()

    def on_stop(self):
        """Called by button thread on stop press."""
        with self._lock:
            if self._state == PlaybackState.PLAYING:
                logger.info("Stop button pressed")
                self._player.stop()

                if self._current_log_id:
                    self._db.log_playback_end(self._current_log_id, completed=False)

                self._leds.off()
                self._cleanup_state()

    def _cleanup_state(self):
        self._current_log_id = None
        self._current_media_id = None
        self._current_tag_uid = None
        self._was_last_video = False
        self._state = PlaybackState.IDLE
        self._leds.idle()
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

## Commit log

2026-02-25 Initial commit: BabyBox project with product website
    Includes hardware designs (OpenSCAD), software, specs, and a static product website.
    [babybox-case.scad, base-template.scad, common-params.scad]
2026-02-25 Add detailed electronics assembly guide page
    New assembly-guide.html with 9 sections: BOM, GPIO wiring reference
    with color-coded pin diagram, 3D printing instructions, hidden magnet
    insertion procedure, electronics mounting guide, complete wiring tables
    with wire colors, figurine construction, 16-step final assembly timeline,
    and safety notes. Includes inline SVG diagrams for GPIO header, enclosure
    top view, lid bottom view, magnet cross-section, and wiring overview.
2026-02-25 Add Blender render assets and display render on homepage
    - Add renders directory with STL models, render script, and output PNG
    - Add render image to website images
    - Update index.html to show the 3D render on the landing page
    [body.stl, figurine.stl, lid.stl]
2026-06-10 Fix Bluetooth speaker connection on headless Pi with WiFi active
    The speaker could never connect because of three compounding issues:
    1. PulseAudio never ran: it is a per-user service that only starts on
    login, but BabyBox runs headless as system services. With no audio
    server, bluetoothd registers no A2DP sink endpoint and rejects all
    speaker connections (br-connection-profile-unavailable). Fix:
    setup.sh now enables lingering for the pi user and the PulseAudio
    user units, and both services pass XDG_RUNTIME_DIR so pactl/mpv can
    reach the session.
    2. WiFi/BT coexistence: the Pi Zero 2 W shares one 2.4GHz radio and
    antenna between WiFi and Bluetooth. WiFi power-save (on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
    [bluetooth.py, bt_autoconnect.py, player.py]
2026-06-25 Add BabyBox README for portfolio
    Full-stack overview: figurine-driven toddler media player — embedded
    Python service with mock/real hardware abstraction, Flask parent UI,
    parametric OpenSCAD enclosure, and Bluetooth audio routing.
2026-06-26 Fix BabyBox install on Raspberry Pi OS Trixie (Debian 13)
    A fresh install on Trixie surfaced three issues that prevented the app
    from starting on real hardware:
    1. setup.sh: Trixie marks the system Python as externally-managed
    (PEP 668), so `pip install --user` is refused. Add
    --break-system-packages; deps still land in the pi user's ~/.local,
    which the systemd services pick up via the per-user site.
    2. babybox.service: rpi_ws281x drives the WS281x LEDs via PWM+DMA
    through /dev/mem, which needs root, but the service runs as User=pi
    (required to reach the pi user's PulseAudio/Bluetooth session). The
    app crash-looped on "ws2811_init failed (mmap)". Grant just
    CAP_SYS_RAW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
    [rfid.py]
2026-06-26 setup.sh: unblock Bluetooth rfkill; install current yt-dlp + deno
    Two more issues found bringing up a fresh Trixie device:
    - Bluetooth radio was rfkill soft-blocked on the fresh image, leaving the
    adapter "off-blocked". `bluetoothctl power on` (used by the speaker scan
    and bt-connect) then silently fails and no devices are ever found. Add
    `rfkill unblock bluetooth`; systemd-rfkill persists it across reboots.
    - YouTube downloads failed (SABR / "Requested format is not available").
    The apt yt-dlp is frozen and goes stale within weeks. Stop installing it
    from apt and instead drop the current standalone binary into
    /usr/local/bin (ahead of apt on the systemd PATH). Modern yt-dlp al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
2026-06-26 Fix YouTube downloads OOM-killing deno on the Pi Zero 2 W
    After installing deno, downloads still failed: the kernel OOM-killed the
    deno process (exit -9 -> "This video is not available") because its
    default V8 heap balloons past the 512MB Pi Zero 2 W's available RAM.
    - babybox.service: set DENO_V8_FLAGS=--max-old-space-size=128 so deno's
    heap stays within memory while still being large enough to solve the
    JS challenge. (128 works; 192 still OOMs.)
    - downloader.py: the JS challenge takes ~50s on this hardware, so the
    30s metadata timeout was too tight. Raise it to 120s.
    Verified end to end through /api/download: a YouTube audio download now
    completes and lands in the library.
    Co-Auth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
    [downloader.py]
2026-06-26 Install libmpv so playback works (python-mpv needs the shared lib)
    Tapping a figurine crashed the RFID thread with:
    OSError: Cannot find libmpv in the usual places
    player.py uses the python-mpv binding, which dlopen's libmpv at runtime.
    On Trixie the `mpv` CLI package does not install the libmpv shared
    library, so find_library('mpv') returned None and mpv.MPV() raised.
    Add libmpv-dev to the apt packages. Verified: find_library now resolves
    libmpv.so.2, mpv.MPV(audio_device='pulse') constructs, and audio plays
    to the Bluetooth sink end to end.
2026-06-26 Add volume control to the app
    A volume slider on the dashboard sets the mpv output level (0-100).
    - player.py: Player takes a volume, passes it to mpv on creation and
    applies changes live via the mpv `volume` property; set_volume() clamps
    0-100.
    - controller.py: expose volume / set_volume and report volume in status.
    - web: POST /api/volume persists to settings and applies immediately;
    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
2026-06-26 Fix YouTube downloads: pip yt-dlp + EJS solver + swapfile
    Downloads were failing/stalling on the Pi Zero 2 W for several reasons:
    - The standalone yt-dlp binary (PyInstaller) self-extracts ~40MB into
    tmpfs /tmp on every run, which fails under memory pressure
    ("PYI ... decompression resulted in return code -1"). Switch to the
    pip build, which runs as a plain Python script with no self-extraction.
    - The pip build does not bundle YouTube's EJS challenge-solver script, so
    extraction failed with "n challenge solving failed -> This video is not
    available". downloader.py now passes --remote-components ejs:github so
    yt-dlp downloads and caches it (deno runs it).
    - The metadata solve is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
    [downloader.py]
2026-06-26 Show real download progress/stage instead of a frozen 0%
    Downloads spend ~1-2 min solving YouTube's JS challenge (twice: metadata
    then download) with no byte-progress, so the bar sat at 0% and looked
    stuck. Now the UI shows what's happening behind the scenes:
    - DownloadJob gains a `stage` field; the worker sets it through each phase
    (fetching info, solving challenge, downloading %, converting, saving) by
    mapping yt-dlp's output lines to friendly labels.
    - /api/download/<id> returns `stage`.
    - library.html shows the stage + elapsed seconds, and renders an animated
    indeterminate bar while there is no real % yet (so it reads as working).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
    [downloader.py, models.py]
2026-06-26 Snapshot prior uncommitted work: deploy infra, v2 enclosure, wired-speaker mod
    Captures work that was sitting uncommitted in the tree so it isn't lost:
    - docker-compose.yml + nginx/ (the homelab nginx container that serves the site)
    - v2 "Pebble" enclosure + its renders, hand sketches
    - wired-speaker mod (schematic, wiring-diagram generator, assembly-guide updates)
    [babybox-case-v2.scad, v2-body.stl, v2-lid.stl]
2026-06-26 Add BabyBox v3 "Tower" enclosure: MX buttons, LED halo, heat-set inserts
    New upright tower design drawn from hardware/sketches/. Six printable parts
    (tray / body / top plate / center lid / diffuser ring / 2 round keycaps):
    - Soldered build, no breadboard; brass heat-set inserts throughout (4 full-
    height corner columns, insert at each end: tray bolts up, top plate down).
    - 2x MX (Cherry-compatible) switches with big round custom keycaps
    (play/pause + stop icons engraved).
    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
    [babybox-case-v3.scad, common-params.scad, keycaps.scad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]
2026-06-26 website: add interactive 3D viewer page for the v3 box
    New viewer.html with a Three.js (STLLoader + OrbitControls) scene loading the
    real OpenSCAD-exported STLs. Drag to orbit, scroll to zoom. Toggles for:
    - Show electronics: ghosts the printed shell and reveals proxy Pi Zero 2 W,
    MFRC522, buzzer, MX switches and a glowing 8-LED halo.
    - Exploded view and auto-rotate; reset-view button.
    Falls back to static renders. Linked from the nav + footer on every page.
    Web STLs are decimated copies under website/models/ (~1.6MB total).
    [v3-body.stl, v3-diffuser.stl, v3-keycap-play.stl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]
2026-06-26 viewer: fix canvas overflow — size the WebGL mount to the stage
    The inner #viewer mount had no height, so the renderer read a 0/auto size and
    the canvas rendered at its raw bitmap dimensions, overflowing the page. Make
    #viewer fill the stage (position:absolute; inset:0), force the canvas to 100%,
    and size the renderer from the real client box with a zero-dimension guard.
2026-06-26 v3 redesign: recessed figurine hole, sealed LED ring, shorter box, tiny power hole
    Reworked the enclosure from feedback:
    - Figurine now drops INTO a recessed central hole (no raised lid); the
    MFRC522 mounts flush right under the thin hole floor (~5 mm read stack).
    - LED ring is raised and FULLY SEALED: the flexible strip wraps the hole wall
    and a glued translucent diffuser caps the top + outer face — nothing exposed
    for little fingers to pick.
    - Box is only as tall as needed (body 32 mm, ~47 mm overall vs ~95 before);
    footprint squared to 90x90 so the RFID board clears the corner columns.
    - Back opening shrunk from a 50 mm service slot to a small rounded-rectangle
    power-cable hol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
    [babybox-case-v3.scad, v3-body.stl, v3-diffuser.stl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]
